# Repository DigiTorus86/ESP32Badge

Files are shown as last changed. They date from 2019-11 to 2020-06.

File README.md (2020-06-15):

# ESP32Badge
Source code and resources for the ESP32 Conference Badge

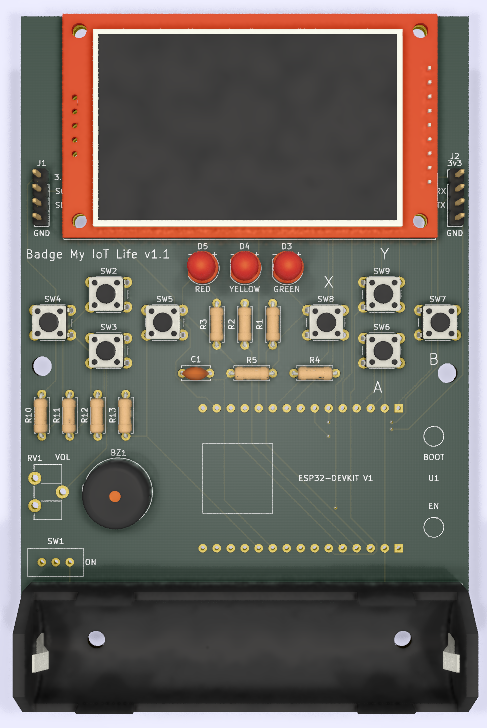
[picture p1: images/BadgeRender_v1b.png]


Requires the ESP32 conference badge or similar hardware:
- PCB:  https://www.pcbway.com/project/shareproject/ESP32_Conference_Badge_v1_2.html
- ESP32 DEVKIT v1 w/30 pins or DevKitC w/38 pins (other ESP32 boards can be used with minimal PIN changes)
- ILI9341 320x240 TFT
- [8] Tactile momentary buttons
- [4] 4k7 resistors (button pullups)
- [3] 5mm LEDs (one each of red, yellow, green)
- [3] 100R resistors (LED current limiters)
- small speaker/active buzzer  (8 Ohm / 2 Watt)
- CR18650 battery and battery holder are optional
- Some sketches have additional hardware requirements (components attached to I2C or Serial pins, or SD card)
- PCB is available at PCB Way for order:
  https://www.pcbway.com/project/shareproject/ESP32_Conference_Badge_v1_2.html

Required Libraries for Arduino platform sketches:
- Adafruit GFX
- Adafruit ILI9341
- ArduinoJson
- XTronical XT_DAC  https://www.xtronical.com/the-dacaudio-library-download-and-installation/

Example Sketches:
- Basic:  4 Simple badges combined into one (Marquee, Hello, Hello w/changing message, Gangster wanted poster)
- Framework Only:  Starter sketch with only pin defines, component setup, and button checking.
- Gravitack:  Low-gravity lunar lander type game
- QR Code:  Name badge with QR code display of the ESP32 IP address and simple web page for controlling the LEDs
- Slideshow: Timed slideshow display.  Requires v1.2 of the badge with 38-pin DevKitC and an SD card.
- Test1:  Test app to verify functionality of the badge.  Also available for the ESP-IDF platform. 
- Test BLE Peripheral/Central:  Shows how to use one badge to control another over BLE.
- Time & Weather:  Displays time and weather data from DS3231 RTC and BME280 temperature/humidity/pressure sensor via I2C as well as network weather info
- Tombstone:  Classic Morg-shooting schooner game
- Wizard:  Animated badge for wizards and witches that have escaped from notorious magical prisons

Accessories:
- Kickstand:  Minimalist 3D-printed kickstand for the badge to get it to stand upright on a flat surface.  Attach to the middle holes on badge (just below the buttons) with 2 small flat-headed woodscrews.
- Case bottom designed by Gino Melone:  https://www.tinkercad.com/things/hnff6LtKR47

Scripts:
- img-rgb565.py: convert graphics files to RGB565 bitmap integer array C header files
- wav-pcm8.py: convert 8 bit mono PCM wave files to byte array C header files 

Additional Info:
- The TFT display orientation is rotated 180 degrees between the v1.1 /DevKitv1 board and v1.2 DEVKITC versions.  Adjust the SCREEN_ROT value in esp32_badge.h to 1 for v1.1 or 3 for v1.2 boards.  
- SD card slot on the TFT is not connected in v1.1

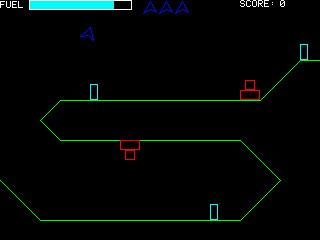
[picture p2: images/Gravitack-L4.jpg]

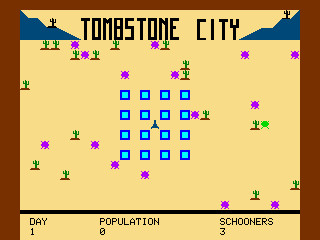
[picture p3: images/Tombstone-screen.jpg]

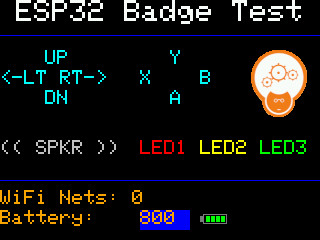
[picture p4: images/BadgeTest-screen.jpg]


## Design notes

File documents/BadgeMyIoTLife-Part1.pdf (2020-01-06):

# Badge My IoT Life - Part I

Paul Pagel

# About Paul Pagel

- 20+ years of developing software professionally
and managing software teams
- Manufacturing Systems Architect at First Solar, Inc.
- Martial arts instructor, former infantry reserve officer
- Particular area of electronic/hardware interest = Audio & Video
- Email: pjpagel86@gmail.com

# Session Objectives

Learn/review the basics of working with electronics and microcontrollers
- Terminology
- Schematics and pinouts
- Soldering and assembly techniques
- Testing and troubleshooting hardware
Build and test a working wireless-enabled conference badge!

# Session Guidelines

- This is an interactive workshop. Be an active participant.
- If I ask a question to the group, go ahead and call out the answer.
- If you have a question, raise you hand…the sooner the better.
- Acronyms and abbreviations - now in nested varieties...
- Work with the session assistants and participants around you during the assembly and testing process. Leverage the wisdom of teams.
- Be respectful of your fellow attendees and keep side conversations to a minimum during the lecture portions.
- Set phones on vibrate and step out to take calls.
- Have fun!

# The Badge

Begin with the End in Mind

# The Badge

### - Think hackable internet-enabled Game Boy with options to add your

own sensors and accessories.

### - Can expect 6 to 8 hours of operation with a fresh, fully-charged

battery.
- Layout facilitates easy soldering.

### - Designed so that key components can be removed and reused in other

projects.

# The Badge – Capabilities

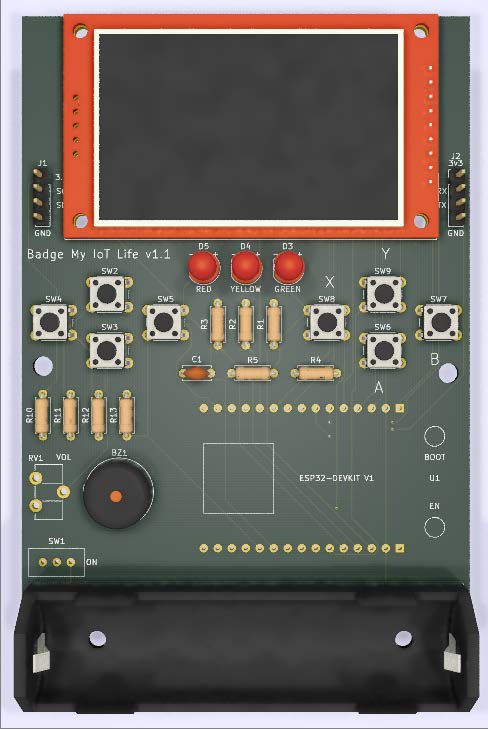
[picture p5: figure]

- Relatively large 262K color display - WiFi and Bluetooth/BLE (Bluetooth Low Energy) connectivity - Lots of buttons for user input - Can be powered from battery or USB - Battery level detection circuit - Digital audio/WAV file output to speaker - Jumpers for Inter Integrated Circuits (I2C) bus and Universal Asynchronous Receive Transmit (UART)

# The Badge – Limitations

### - Rather bulky compared to coin cell

powered badges with e-Ink displays.

### - Don’t expect 60 Hz display refresh (closer to 1 Hz for full screen) - Fairly quiet, low-fidelity sound from

the button speaker/transducer.

# The Badge Tester App

### Allows you to easily exercise all the buttons and peripherals on the badge

and detect any problems.

### Comes pre-loaded onto the

microcontroller included in the kits.

### This should be the first thing you see when you power on your completed

badge.

# Microcontrollers

A Quick Overview

# Microcontrollers

### Microcontroller: A small computer on a single integrated circuit often used in embedded applications. Also referred to as a Micro

Control Unit or MCU.

A few common examples:
- Atmel AVR
- ARM Cortex M-series
- ESP8266 / ESP32-Wroom-32 Come in a number of form factors
- Dual Inline Package (DIP)
- Surface Mount Devices (SMD)

# Development Boards

### Dev boards are designed to make the MCU easier to evaluate and to

use in small scale custom designs.

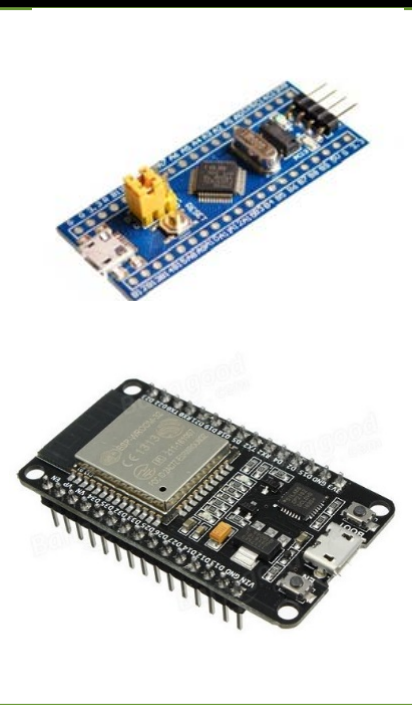
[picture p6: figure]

### Common examples: - Arduino Uno - Adafruit Feather

### - STM32F103 “Blue Pill” - ESP32 Dev Kit

# Meet the ESP32 DevkitC/NodeMCU-32S

## Processing power and memory

### - Espressif ESP WROOM-32D MCU

### - Dual-core 32-bit Tensilica Extensa LX6 processor @ 160 or 240 MHz - 448KB ROM, 520KB SRAM, 4MB Flash

In Kit:
- 1 – ESP32 DevKitC w/38 pins

# Meet the ESP32 DevkitC/NodeMCU-32S

## Excellent connectivity capabilities

### - 2.4GHz dual-mode WiFi + Bluetooth 4.2 + BLE

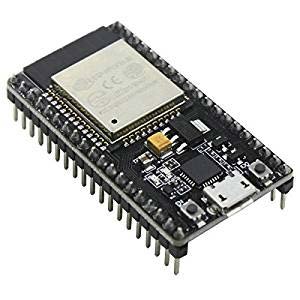
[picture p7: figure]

### - Support for security and encryption

# Meet the ESP32 DevkitC/NodeMCU-32S

## Many built-in peripherals

### - Integrated UART, SPI, I2C, I2S, CAN, PWM

### - 18-channel 12-bit Analog-to-Digital Converter (ADC) - 2-channel 8-bit Digital-to-Analog Converter (DAC) - 30+ General Purpose Input Output pins (GPIO)

# Electronic Components

What’s in the Kit and What It Does

# Printed Circuit Board (PCB)

### - Contains attachment points / through-holes for components and the wiring traces to

connect them.

### - Silk screen identifies the location and

orientation for components to be soldered.

### - Allows for quicker assembly, fewer mistakes, and smaller footprint compared

to proto or strip board.

In Kit:
- 1 – custom PCB (v1.2)

# PCB Structures

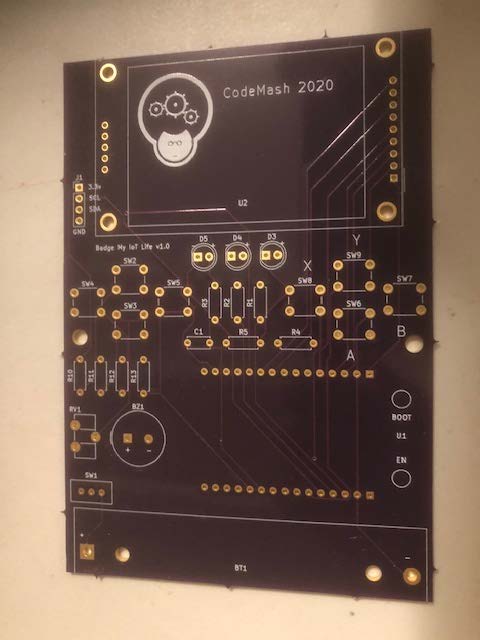
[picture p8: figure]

### Solder Mask - Top layer that repels solder and protects the traces - Often contains lead, so don’t lick it

# PCB Structures

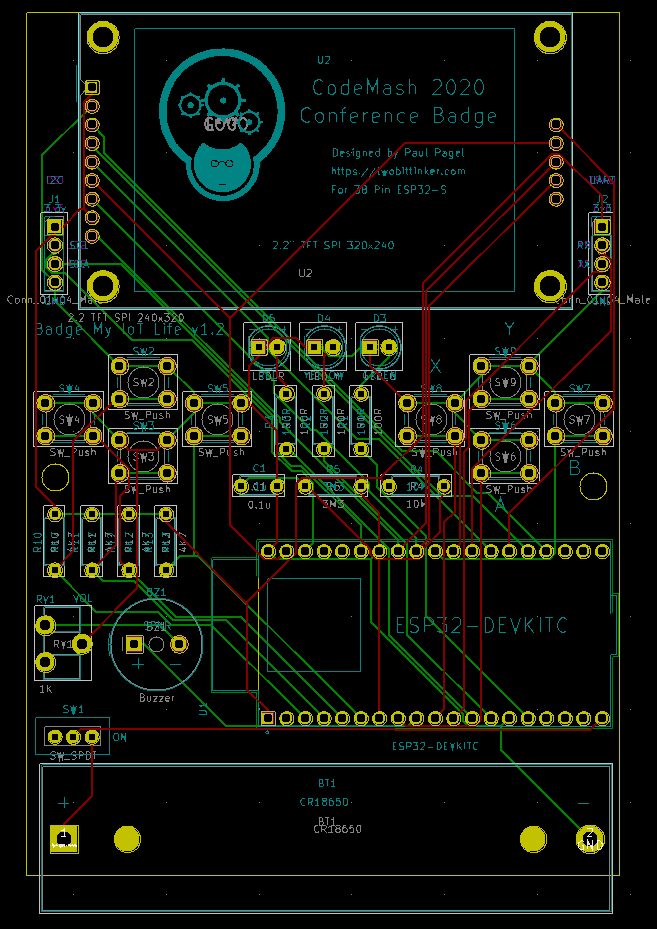
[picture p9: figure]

### Traces - Copper wires that connect the solder pads/rings - The badge board has 2 layers of traces (front & back) - Traces can be damaged

# PCB Structures

### Through Holes

### - Mounting holes: large, may or may not have metallic annular rings. Used to

connect cases, peripherals, etc.

### - Component holes: sized to accommodate component wires (~22 gauge) and always have an annular ring

for soldering.

### - Vias: smaller holes that allow the traces to carry current from one layer to another. Not for soldering!

# Schematic v1.2

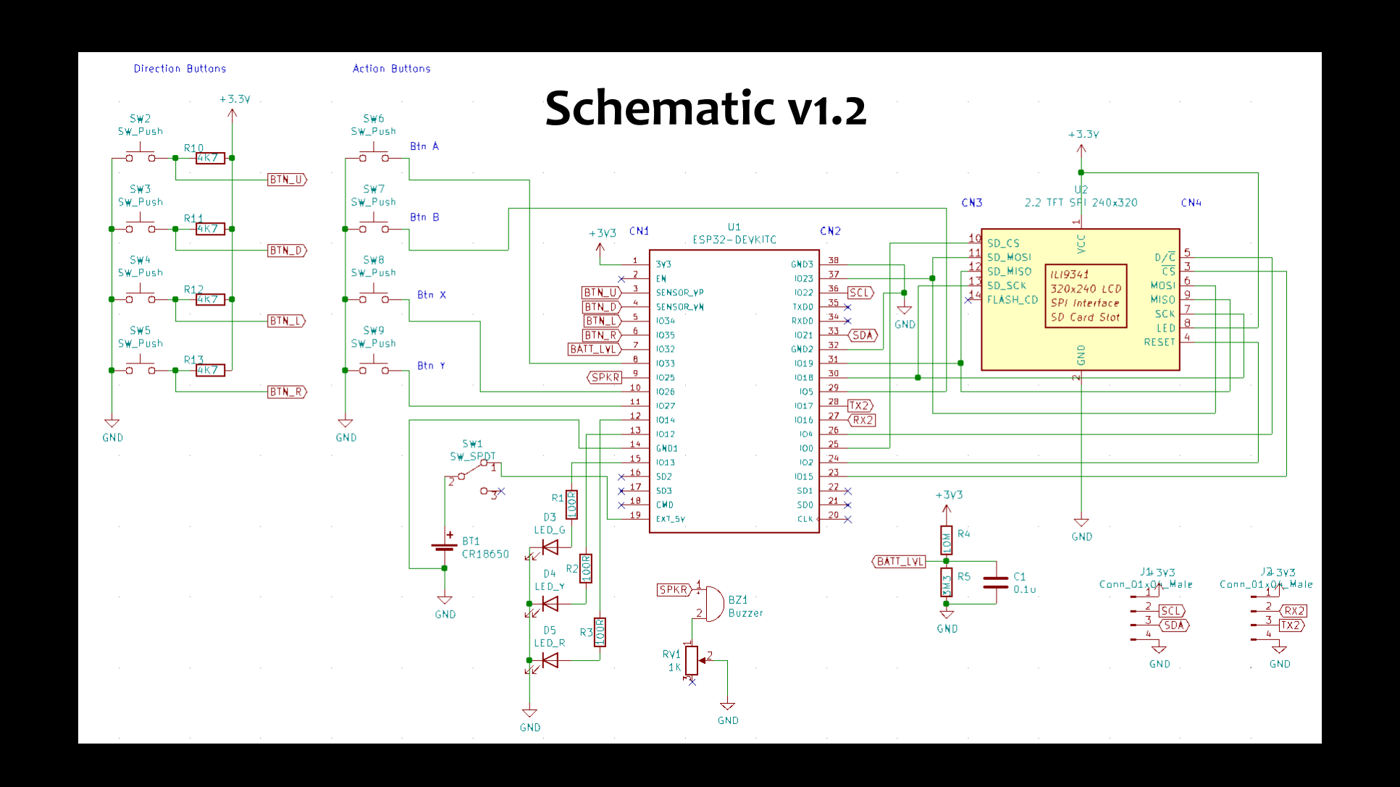
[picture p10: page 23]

# Matching the Schematic to the PCB

### - The schematic can help identify the role of each component on the PCB - Component identifiers on the schematic match up to those on the PCB and BOM (Bill of Materials)

SW1 = Switch1, R1 = Resistor1, C1 = Capacitor1, etc.

### - Schematic circuit is easier to follow than the traces on the PCB and is useful for diagnosing problems or determining if a substitute component can be used - The physical pin layout on the PCB may be different from the logical pin layout on the schematic

# TFT LCD Screen

### Thin Film Transistor (TFT) Liquid Crystal Display (LCD)

- Usually have a specific control chip, i.e. ILI9341
- Often include an SD card reader on the back
- May or may not have touch capability (T_ pins)
- Often use Serial Peripheral Interface (SPI) protocol for communication with the MCU
- Frame rate vs low resource utilization tradeoffs

In Kit:
- 1 – TFT LCD, 2.2” 320x240 w/integrated ILI9341 SPI
controller, 3.3v, 262K colors [U2]

# 18650 Lithium Battery

### 3.7 v lithium rechargeable battery - 18650 indicates 18mm diameter x 65mm height - Voltage output range is 4.2v – 2.5v, which pairs nicely with 3.3v MCUs - Capacity is measured in mAh (milliamp hours) and maximum continuous

discharge in Amperes.

### - These are inversely related. Generally

favor capacity for MCUs.

In Kit:
- 1 – 18650 3.7v rechargeable battery

# Battery Holder

### Holds battery in place and provides electrical connection between battery and circuit board Polarized – pay attention to + / -

In Kit:
- 1 – 18650 battery holder [BT1]

# TP4056 Battery Charger

### 5v 1A micro USB board for recharging CR18650 batteries

- Allows you to charge the battery without having to remove it from the badge
- Optional – not required

In Kit:
- 1 – TP4056 charging module
- 2 - hookup wires (+ / -)

# Piezo Buzzer/ Electrodynamic Speaker

### Generates tones or other sounds

Two general types
- Active – generates tones based on DC voltage
- Passive – requires oscillating input to convert to sound Polarized – positive leg marked with a (+) on top or bottom

In Kit:
- 1 passive speaker
(polarized) [BZ1]

# Resistors

### Passive device used reduce current or divide voltages

- Non-polarized (no right or wrong orientation)
- Measured in Ohms
- 100R indicates 100 Ohms
- 4K7 indicates 4,700 Ohms
- 3M3 indicates 3,300,000 Ohms
- R10 – 13 can be 2k – 8k Ohm
- R1-3 can be 100 – 330 Ohm

In Kit:
- 4 – 4k7 [R10-13]
Ye-Vi-Bk-Br
- 3 – 100R [R1-3]
Br-Bk-Bk-Bk
- 1 – 3M3 [R5]
Or-Or-Bk-Ye
- 1 – 10M [R4]
Br-Bk-Bk-Gr

# Breaking the Code

### Many mnemonics available. One example: Bright Boys Rave Over Young Girls But Veto Getting Wed

When in doubt,

### measure with a

multimeter.

# Potentiometers

### Variable resistors

- Can be rotary (dial) or linear (slide)
- Middle leg is connected to the wiper (C)
- Markings indicate maximum resistance
- First 2 digits x 10^3rd digit
- 501 = 50 x 10^1 = 500 Ohm
- 102 = 10 x 10^2 = 1k Ohm

For the badge, any value from 500 to 2000 Ohm will work.

In Kit:
- 1 – 1K pot
[RV1]

# LEDs

### Light Emitting Diodes

- Polarized - orientation is critical
- Longer leg = positive
- Flat side = negative (may not be present)
- Popular sizes are 3mm, 5mm, and 10mm
- Usually require a current-limiting resistor

In Kit:
- 1 – Red [D5]
- 1 – Yellow [D4]
- 1 – Green [D3]

# Capacitors

Passive devices that store electrical energy
- Some types are polarized, others are not
- Ceramic = non-polarized
- Electrolytic = polarized
- Measured in Farads
- nF = nano Farads (1 billionth)
- uF = micro Farads (1 millionth)

In Kit:
- 1 – 100nF / 0.1uF ceramic capacitor [C1] (usually marked with a “104”)

# Buttons and Switches

Mechanical devices for opening and closing a circuit
- Momentary vs. Latching
- Normally Open (NO) vs. Normally Closed (NC)
- Poles = number of circuits connected
- Throw = number of positions (on/off is single)

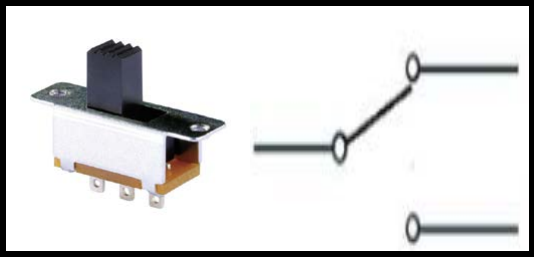
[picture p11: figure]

SPDT slide switch
(Single Pole Double Throw)

Tactile momentary
NO button
(Normally Open)

In Kit:
- 1 – SPDT slide switch (power) [SW1]
- 8 – momentary NO buttons [SW2 - 9]

# Header Pins

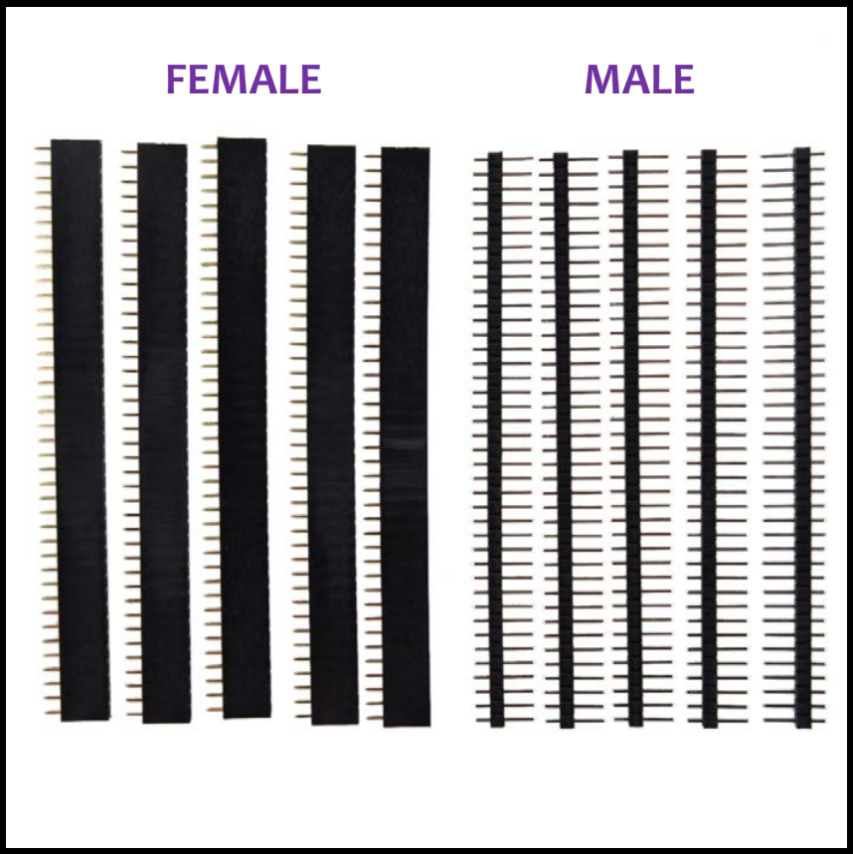
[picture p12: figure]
FEMALE; MALE

Connect controllers, breakout boards,

### major components, and jumpers

- Come in male and female varieties.
- The short end goes into the PCB

In Kit:
- Female header pins
- Male header pins

# Soldering

Bringing the Heat Without Getting Burned

# Soldering Iron

- Tip needs to heat up to about 700F / 370C before use.
- Keep the tip lightly tinned (shiny) but not gobbed with solder.
- Use the scouring pad to remove excess solder from the tip.

# Soldering Iron

### Safety

- Only pick up by the handle.
- Practice good tip control at all times - no balancing, waving, or gesturing with the iron. It’s not a wand.
- Keep cords clear of obstacles.
- Don’t set down on table – always use the provided stand.
- Don’t hand it to another person. Let them pick it up.
- Turn the iron off/unplug before leaving your station.

# Solder

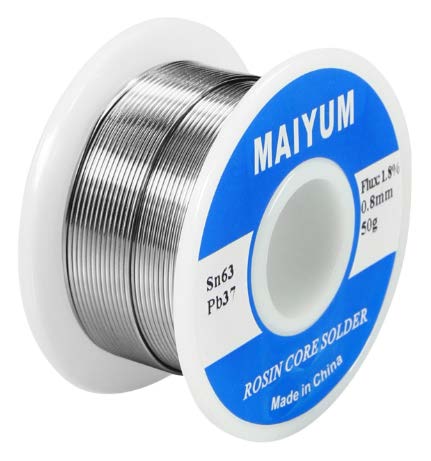
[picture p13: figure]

- Most common solder for hand-soldering is a mix of tin (~60%) and lead (~40%)
- Rosin core allows the melted solder to flow smoothly onto the pads and wires
- Rosin has the downside of producing smoke that is a lung irritant – avoid inhaling.
- Lead-free wire is available, but requires a higher melting temperature and is more difficult to work with.

# Soldering Technique

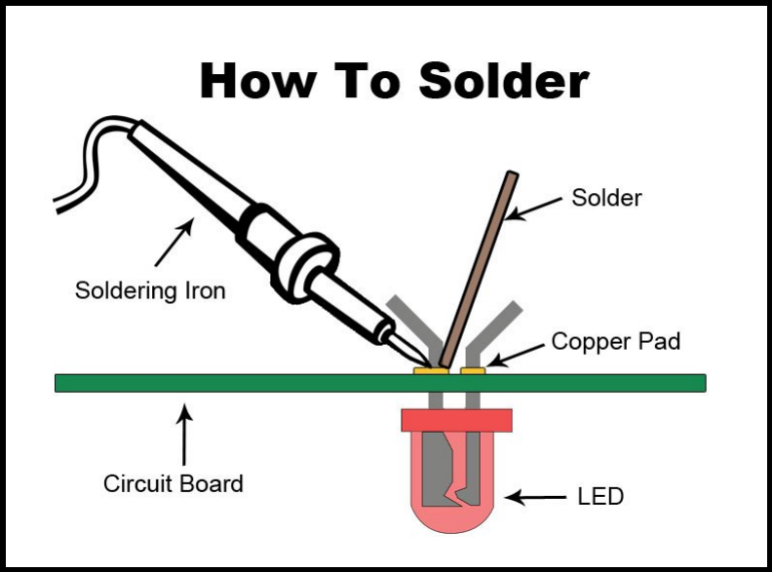
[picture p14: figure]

- Heat both of the elements that you are soldering (i.e. the solder pad and the component wire) for a few seconds, then apply the solder.

Solder flows towards heat!
- Don’t keep applying heat to components for more that a few seconds or you may damage them.

# Soldering Technique

- Ensure you have a smooth, shiny, volcano-shaped join and that all
the gaps are filled in.
- Watch out for solder
bridges/shorts to other pads or components.

# Soldering Technique

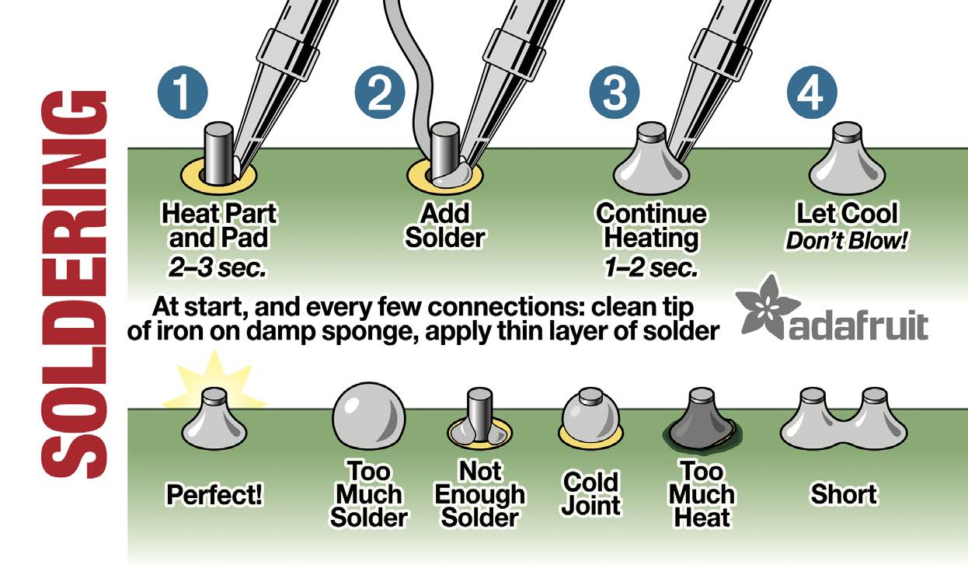
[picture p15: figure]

# Flush Cut Pliers

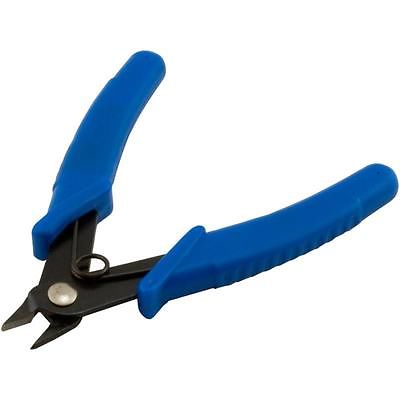
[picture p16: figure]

### Trim component lead wires after soldering

- Leads and pins often separate at high speeds and go flying, so cup them with your hand and don’t point them at your eyes while using.
- Keep wire cuttings and waste in your plastic cup – not scattered around on your table.

# Desoldering

Dealing With “Oops!”

# Desoldering Pen (aka Solder Sucker)

### Used to suck away solder when removing

soldered components.
- Use the plunger to prime the pen, and the button to perform the suction operation.
- Requires a bit of precision and timing as nozzle needs to be pretty close to the liquefied solder and triggered before the solder starts to solidify.
- Often requires multiple attempts to get most of the solder.

# Desoldering Braid/Wick

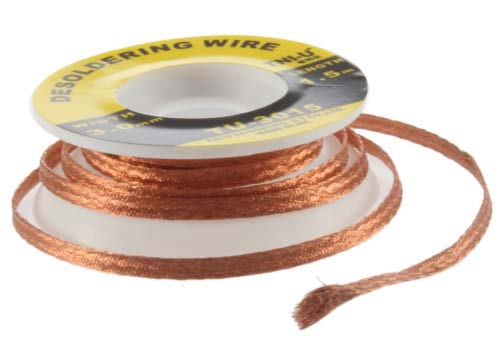
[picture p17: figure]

### Used to pull away solder when removing

soldered components.
- Use a section of the braid without solder on it.
- Heat the solder through the braid to get the solder to melt and flow onto the braid and then pull it away from the area.

Remember, solder flows towards heat.

# Desoldering

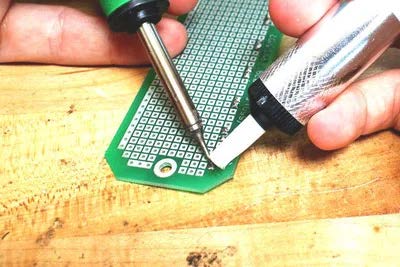
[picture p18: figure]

1. Reheat the joint and get as much solder away from it as you can using a desoldering pump.
2. Alternatively, heat joint through a soldering wick/braid to get the solder to stick to the wick.
3. Use a pliers to gently pull the component wires from the board.
4. Reheat and remove any excess solder that is still left using solder braid.
5. Insert and solder the replacement component.

# For a More Pleasant Experience…

- Take your time. This isn’t a race. No points awarded for finishing first.
- Help others around you. No soldier or (solderer) gets left behind.

### - Cup up = working on badge - Cup down = done and good to go Please put your trimmings/waste in the garbage can first!

# Assembling the Board

Putting It All Together

# General Assembly Guidelines

- Keep parts segregated to avoid confusion (especially resistors)
- Start with the smaller/shorter passive components and work towards the larger ones
- Bend resistor leads to a 90 degree angle as close to the body as possible
- If you’re not sure about a resistor’s value, use a multimeter to test it.
- Pay close attention to polarity! (LEDs, speaker, battery)
- Even though orientation doesn’t matter for non-polarized components (like resistors) it’s easier to identify them on the board if you orient them consistently.
- Check twice, solder once – always on the back of the board. Desoldering is a bit of a pain.
- Don’t trim leads until after you’ve soldered and inspected them
- Use magnification to check for breaks, shorts, solder bridges, splashes, etc.

# Detailed Assembly Instructions - 1

1. Identify the (4) 4.7K Ohm button pull-up resistors (yellow, violet, black,
brown) . Place them in the board,
bend the ends out slightly, and solder in place.
2. Next the (3) 100 Ohm current-limiting resistors (brown, black, black, black) for the LEDs
3. Then the 3M3 (orange, orange, black, yellow) and 10M resistors (brown, black, black, green) and the .1 uF ceramic capacitor for the battery level voltage divider
4. Solder, inspect, and trim leads.

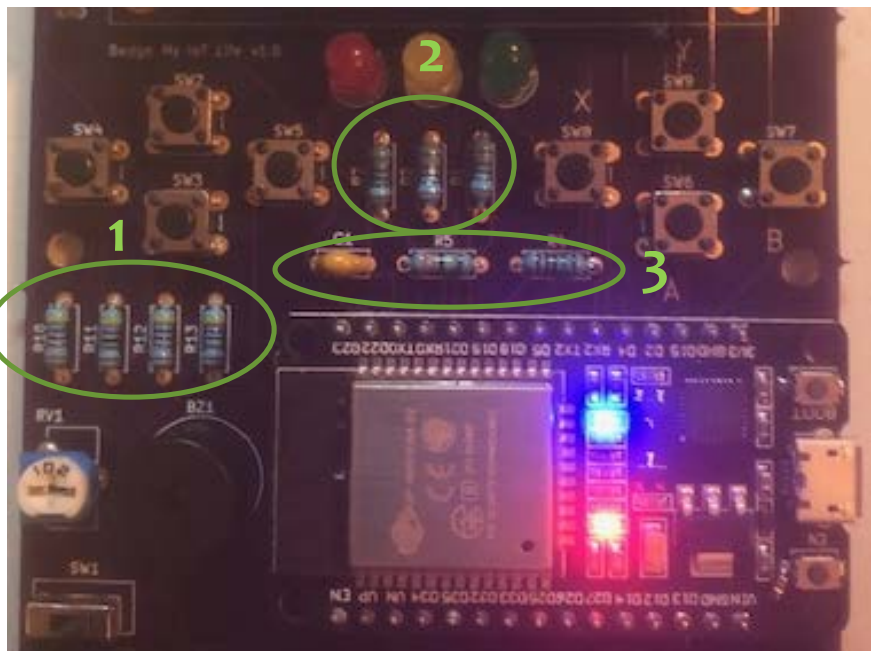
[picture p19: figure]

# Detailed Assembly Instructions - 2

5. Place the 4 direction and 4 action
buttons. The buttons will only fit with
the legs oriented left/right.
6. Insert the 3 LEDs as shown. Make sure the longer leg goes to the hole on the right (marked + )
LEDs can be destroyed by too much heat, so don’t keep the soldering iron touching the led leads for more than a few seconds at a time.

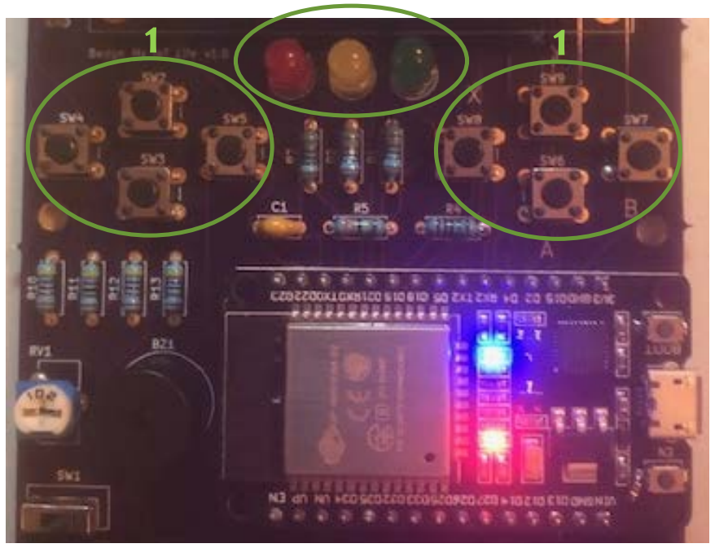
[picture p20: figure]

7. Solder, inspect, and trim leads.

2

# Detailed Assembly Instructions - 3

8. Add the on/off SPDT switch.
Don’t worry about polarity.
9. Insert the 1k Ohm trim pot (102)
10. Add the speaker. Pay attention to the polarity (+ lead to + hole) You may want to cover the
speaker hole with a piece of cellophane tape to increase volume.
11. Solder, inspect, and trim leads.

1

# Detailed Assembly Instructions - 4

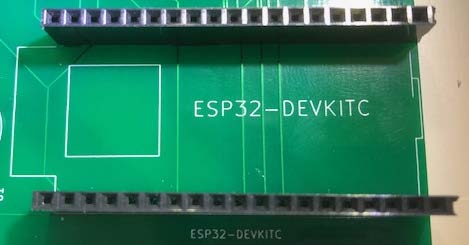
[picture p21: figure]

12. Insert one row of pins on the
ESP32 into the female header
pins as shown. Trim to header to
proper length (19 pins for v1.2)
13. Repeat for other row of pins on the ESP32.
14. With the female header pins attached to the ESP32, insert them into the board with the USB port to the right. Painter’s tape is useful to hold the ESP32 in place as you solder the header pins.

# Detailed Assembly Instructions – 5

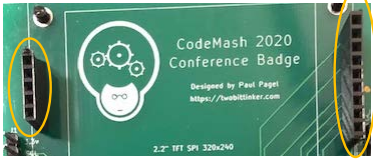
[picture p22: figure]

15. Cut male and female header pins
for the TFT display.
16. Insert the male pins into the female pins, then place the TFT over the short ends of the male pins and solder them to the TFT. It will help to have the ends of the female pins inserted into the board as you solder the TFT.
17. Flip the board over and solder the female pins to the board. Painter’s tape may help to hold everything in place.

# Detailed Assembly Instructions - 6

18. Solder the battery holder to the
board. Mind the polarity ( + to
the left) Suggest marking
polarity with metallic marker. Go fairly heavy with the solder as this part will be subject to mechanical stress.
19. Take a 4 pin male header for the I2C bus and solder to the left of the TFT.
20. Take another 4 pin male header for for the RX/TX header on the right and solder in place.

# Detailed Assembly Instructions - 7

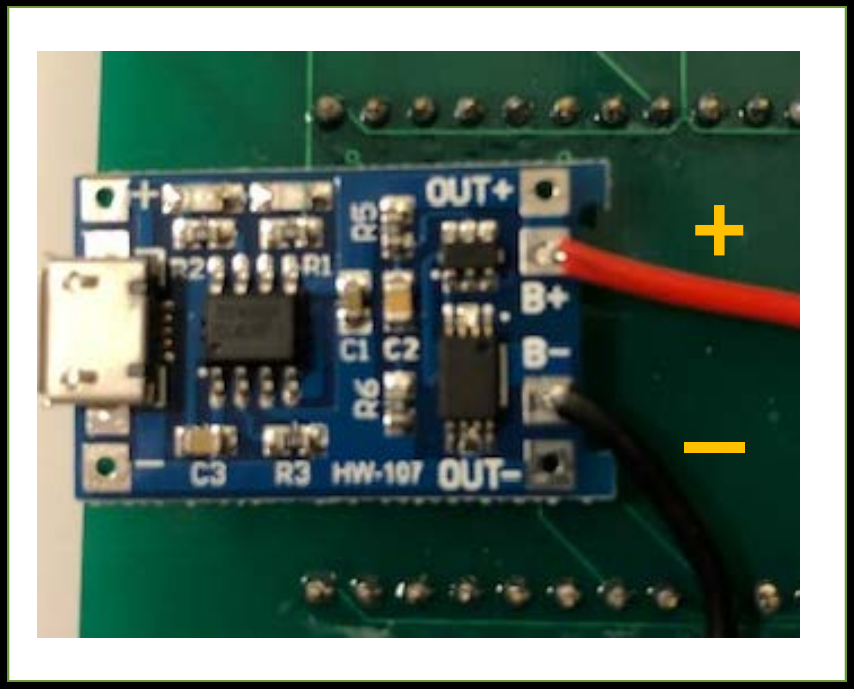
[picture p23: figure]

### OPTIONAL – Battery Charger

21. Solder the positive lead wire to the B+ pad on the TP4056 module, and the negative lead to the B- pad.
22. Stick the TP4056 to the back of the badge using double-sided tape.
23. Solder the wires to the corresponding battery holder terminal. Note that positive is on the right when looking at the back.

# Final Check

### Before energizing your badge, double-check: - ESP32 orientation (USB port to outside of board) - Battery holder and charger polarity are correct and clearly marked - All wires and pins have been soldered - No solder bridges are present

### Have one of the session assistants or an experienced neighbor

perform a final check on your board.

# Testing

Keep Your Fingers Crossed

# Booting the Assembled Board

1. Hook up the ESP32 controller to
your laptop or 5v / 1A DC power
source using the Micro USB
cable.
2. The badge test app should boot up after a few seconds.
3. If not, try pressing and releasing the EN button below the micro USB port.

# Testing the Assembled Board

1. Network count will be 0 initially. Battery level should be around 800 or higher and stable. Zero or a wildly fluctuating value indicates a problem.
2. Press all the buttons and verify that the corresponding element is highlighted on the screen while the button is pressed.
3. The following buttons have additional actions that should be triggered:
- X: Red LED
- Y: Yellow LED
- A: Green LED
- B: Tone should play through the speaker
4. You may need to adjust the trimpot to get the desired volume. Counterclockwise = Louder (Be gentle – don’t force it!)

# Testing Battery Operation

1. Disconnect the USB cord from the ESP32.
2. Ensure the power switch is in the “Off” position (all the way to the left)
3. Place the loop of ribbon across the battery holder perpendicularly. (Not required if you have exceptionally strong fingers or enjoy the challenge of battery extraction.)
4. Take a charged CR18650 battery and insert it with the positive end pointed towards the left side of the board and firmly seat in place.
5. Move the switch to the “On” position.
6. Repeat the previous button test.
7. Verify that the battery level indicator is lower than what was shown in the previous test. Usually it will be under 1000.

# Troubleshooting – Dead Board

### If you get no response from the badge at all:

- Remove the ESP32 from the badge and see if the power light comes on when hooked up to your laptop via the USB cable
- Ensure you have the ESP32 oriented on the board correctly with the USB port to the right
- Swap your ESP32 with a different one
- Swap out your TFT display
- Swap out your USB cable
- Connect the USB to a 5v 1A transformer (i.e. iPhone charger) instead of your laptop

Change only 1 element/test parameter at a time.

# Troubleshooting Components

If the badge works, but one or more particular components are non-functional:
- Re-examine the solder joints, looking for shorts/solder bridges (preferably under magnification)
- Scrub the back of the board lightly with a brush to remove an fine solder splashes/shorts.
- Ensure you have the polarity correct (battery, LEDs)
- Re-heat/re-flow the solder for the non-functional component
- Verify the component using a multimeter
- Look for discolorations that indicate an LED is burned out
- Test LEDs using a regulated power source.
- Swap out the component with a verified operational one

Use the schematic to help identify the components that may be involved in the failure!

# Charging Your Battery

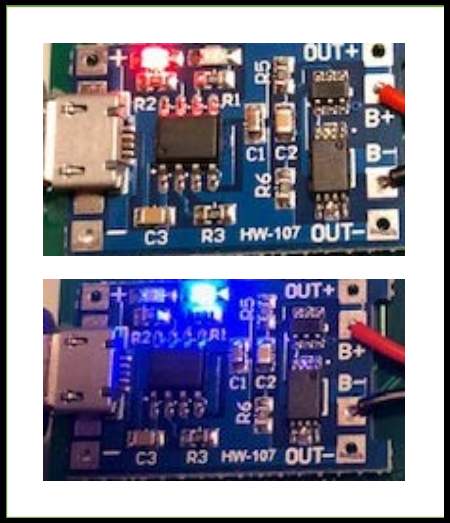
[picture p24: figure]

1. Connect a micro USB cable to the charger and a 5v DC power source.
2. LED on the charger will show red when charging.
3. The blue LED will come on when the battery is fully

-charged.

The charger has built

-in overcharge
protection, but should *not* be used to drive loads while charging (which would negate this feature).

Charging

Charged

# Finishing Touches

- Snap in the black plastic badge hanger to the top 4 holes on the back of the badge.
- Clean up your area and put your trimmings/waste in the garbage.

# Interface Protocols

A Small Byte of Serial

# Common Interface Protocols

### Standardized methods and wire layouts for communicating with other systems, peripherals, and sensor breakouts

Common examples:
- UART
- SPI
- I2C
- I2S
- CAN
- USB
- USART
- 1-Wire

# Common Interface Protocols

Do not confuse connector standards with the underlying protocols.

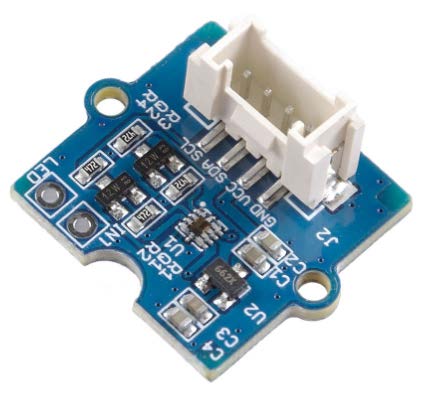
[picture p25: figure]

- Grove
- Qwiic
- Gravity
- MikroBUS
- JST

# Parallel vs Serial

### Parallel requires a pin/wire for every bit

### Serial sends data for a channel over the same pin/wire

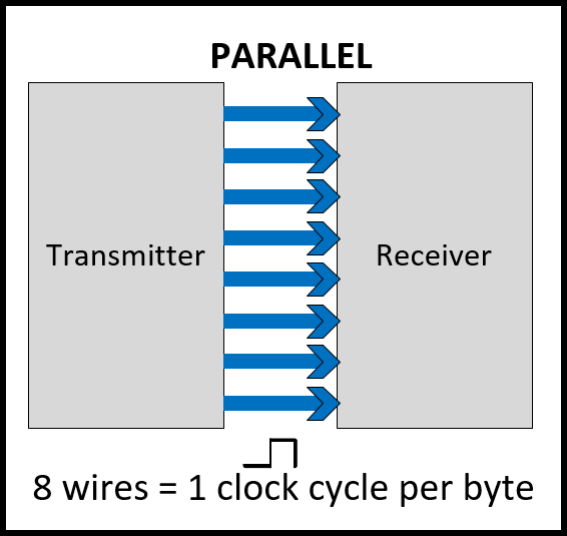
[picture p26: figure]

Serial protocols tend to be much more common with microcontrollers.

# Serial Protocol Hardware Pins

# Universal Asynchronous Receive Transmit (UART)

- Takes bytes and serially shifts them to the receiver,
which then assembles them back into bytes.
- May be simplex (one direction only), half-duplex (one direction at a time), or full-duplex (both directions at the same time)
- Most microcontrollers use full-duplex with separate RX/TX lines
- Must configure both sender and receiver with the correct baud rate.
- May also have options for different data bits, bit
parity, stop bits, and handshakes.

https://core-electronics.com.au/tutorials/serial-communications-arduino-uno.html

# UART – Usage Considerations

- Ubiquitous and easy to use
- Often used for debugging and simple data transmissions between devices
- Other common peripherals include RFID readers, fingerprint scanners, MIDI ports, and BLE adapters.
- Serial UART output can be monitored with a number of standard tools: Arduino Serial Monitor, VS Code terminal, TeraTerm, etc.
- USB to TTL (Transistor Transistor Logic) level UART cables used to program and debug many microcontrollers.

# UART on ESP32

- ESP32 devkit board has 2 UART peripherals broken out (UART 0, UART 2)
- In Arduino environment, initialized with: Serial.begin(baud_rate);
Serial2.begin(baud_rate);
- Unmatched baud rates = garbage data received Pay attention to your serial console/monitor settings:
- On the badge, Serial is accessed through USB and Serial2 via jumper to the right of the TFT

# Serial Peripheral Interface (SPI)

### SPI Pins:

- SCK: Serial Clock (hi/low pulse)
- MOSI: Master Out Slave In
SDI = Slave Data In
- MISO: Master In, Slave Out
SDO = Slave Data Out
- SS: Slave Select or CS=Chip Select ~, n, or bar indicates active low
- Vcc and GND are always assumed
- May have an INT (interrupt) pin
SPI devices can share the same GPIO pins - except for SS

# SPI - Usage Considerations

- Commonly used for displays (TFT, OLED, e-Ink, etc.), storage/SD, lower-end audio applications
- Is full-duplex, so can send and receive data at the same time
- Is synchronous and can use a range of clock frequencies
- Comes in 4 different “flavors” depending
on clock phase and polarity

# SPI on ESP32

Arduino environment uses SPI.h library
- ESP32 has 4 SPI peripherals
- SPI0 & SPI1 used internally
- SPI2 = HSPI, SPI3=VSPI
- Badge uses VSPI
- SS can be any digital GPIO pin
- Most common devices have existing libraries that take the SPI pin
assignments as a constructor

https://learn.sparkfun.com/tutorials/serial-peripheral-interface-spi/

# SPI on Screen

The ILI9341 display adds a couple extra pins to the SPI interface:
- LED: power/brightness for the screen backlight LED
- DC/RS: Data Command/Register Select – tells the TFT the nature of the bits coming across MOSI wire Low = Command
High = Data / Command Parameter
- Reset: Resets the display when low There are also SPI pins for the SD card
(SD_xx) and optional SRAM chip (F_CS)

http://www.lcdwiki.com/2.2inch_SPI_Module_ILI9341_SKU:MSP2202

# Inter Integrated Circuits (I2C)

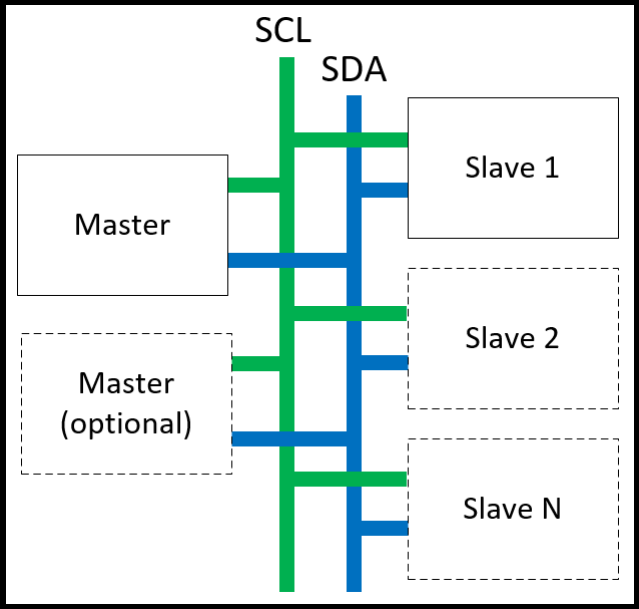
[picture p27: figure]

### Half-duplex “two-wire” serial protocol

- Master always initiates communication
- Pins
- SCL = Serial CLock
- SDA = Serial DAta
- Multiple devices (100+) can exist on the same I2C bus without any additional pins
- Each slave device must have a unique 7-bit address

# I2C – Usage Considerations

- Good for pin-constrained situations (only uses 2 wires) or when you need to control a lot of devices
- Easy to add digital IO expander and ADC chips
- Supports multiple masters with arbitration
- Often used for audio/video/camera control interfaces, but not for the data itself
- A bit more complicated under the hood than SPI

# I2C Driver

Open source hardware tool for controlling I2C devices
- Includes a TFT display of current status/activity
- GUI running on your computer is used to select addresses and read/write data

# I2C – Badge Implementation

Arduino environment uses the Wire.h library for I2C
- Normal high-level process:
Wire.begin();
Wire.beginTransmission(I2C_ADDRESS); …read and write data to/from different registers… Wire.endTransmission();
- Refer to the device datasheet for the registers and commands to read/write.
- On the badge, the I2C jumper pins are to the left of the TFT

# Pulse Width Modulation (PWM)

- Technique used to encode a value on a digital
pin based on the percentage of time the value is
high vs. low.
- The percentage of high vs. low is known as the duty cycle
- PWM is commonly used to dim LEDs, control servos, or drive an audio signal.
- Different applications require different frequencies (how often the voltage changes)
- LED dimming: 100 - 50o Hz (cycles/second)
- Motor driver: 200 – 5,000 Hz
- Audio: 44 KHz+

# Pulse Width Modulation (PWM)

### ESP32 uses the LEDC (LED Control) library

- https://github.com/espressif/arduino-esp32/blob/master/cores/esp32/esp32-hal-ledc.h
- Set up an LEDC channel with a frequency and a timer
- Attach the channel to one or more output pins for the PWM signal
- Write the duty cycle to the channel

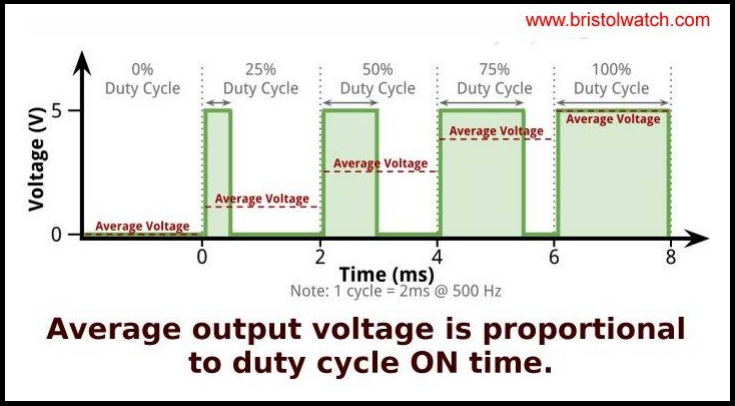
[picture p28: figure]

See the Badge Marquee sketch for an example of using PWM to dim LEDs

# Next Steps

Where do we go from here?

# Finishing Touches

- Take a picture of your completed badge for posterity (selfies will come in the next session when we load and customize the other badge apps)
#codemash2020.

- Prepare for the afternoon session:
- Ensure Arduino IDE or VS Code w/PlatformIO is installed on you laptop
- Make sure you have some image and audio editing software installed
- Check that your laptop recognizes the ESP32 when connected via USB
- Make sure you mobile phone is charged and has a QR code app loaded
- Full prerequisite instructions: http://prereqs.codemash.org/Files/Badge%20My%20IoT%20Life%20-%20Prework.pdf

# Hardware Considerations

- Recommend turning switch to OFF position when the ESP32 is connected to laptop of other power source, as well as when charging the battery via the TP4056.
- The I2C and UART pin headers on the badge support a wide variety of 3v3 peripheral devices. If you have any, you may want to consider connecting them to the badge with female DuPont connectors or soldering hookup wire to female header pins to create a custom connector.

# CodeMash Badge Contest

### Categories

### - Laugh Out Loud - Artistic Achievement - Technical Wizardry

### Bring submissions to the Maker Space before noon on Friday for consideration. CodeMash staff will take a short video, along with

your name(s) and email. Must be present Friday afternoon to win.

# Resources

- Greg Huber’s instructional videos on assembling the badge Part 1: https://youtu.be/l8pbRDcyUmc (https://nam03.safelinks.protection.outlook.com/?url=https%3A%2F%2Fyoutu.be%2Fl8pbRDcyUmc&reserved=0)
Part 2: https://www.youtube.com/watch?v=5SnY-SC2Caw
- Adafruit Guide to Excellent Soldering https://learn.adafruit.com/adafruit-guide-excellent-soldering/tools
- Instructables Ultimate Guide to Desoldering https://www.instructables.com/id/The-Ultimate-Guide-to-Desoldering/
- Espressif ESP32 WROOM-32D Documentation https://docs.espressif.com/projects/esp-idf/en/latest/hw-reference/modules-and-boards.html

# Acronyms

- ADC: Analog to Digital Conversion
- BLE: Bluetooth Low Energy
- DAC: Digital to Analog Conversion
- GND: Ground
- GPIO: General Purpose Input Output (pins)
- I2C: Inter-Integrated Circuit pronounced "I squared C" (serial bus with 2 pins: SCL, SDA)
- I2S: Inter-IC Sound (serial audio protocol with 3 pins: SCK/BCLK, WS/LRCLK, SD/SDATA)
- MCU: Micro Control Unit
- MISO: Master In - Slave Out (SPI pin) sometimes referred to as SDI on a master
- MOSI: Master Out - Slave In (SPI pin) sometimes referred to as SDO on a master
- PCM: Pulse Coded Modulation (WAV files)
- PWM: Pulse Width Modulation
- RXD: Receive Data (UART pin)
- SCK: Serial Clock (SPI pin)
- SCL: Serial Clock (I2C pin)
- SDA: Serial Data (I2C pin)
- SPI: Serial Peripheral Interface (4 pins: SCK, MOSI, MISO, SS)
- SRAM: Static Random Access Memory
- SS: Slave Select (SPI pin)
- TFT: Thin Film Transistor (Liquid Crystal Display)
- TTL: Transistor Transistor Logic (0v/LOW & Vcc/HIGH)
- TXD: Transmit Data (UART pin)
- UART: Universal Asynchronous Receiver/Transmitter (2 pin interface using RXD and TXD pins)
- USB: Universal Serial Bus
- V+ / Vbus / Vcc - Voltage positive signal (USB header pin)
- VREF: ADC reference voltage, usually 1/2 the ADC voltage range, i.e. 1.65v for 3.3v logic

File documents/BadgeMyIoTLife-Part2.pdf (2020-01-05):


# Badge My IoT Life - Part II

Paul Pagel

# Badge My IoT Life – Part II

### GitHub repo: https://github.com/DigiTorus86/ESP32Badge

### Slide Decks and Labs (PDF): https://github.com/DigiTorus86/ESP32Badge/tree/master/documents

# Session Objectives

### - What can the ESP32 badge do? - How can I incorporate my own graphics and digital media? - How do I build a personalized badge application? - How can I use the wireless capabilities of the ESP32? - What are some next steps I can take?

# Out of Scope

## This session will not:

### - Dive deep into the low-level details of MCU architecture or interface protocols - Require expertise with C or C++ (though it will help) - Make you an EE

# Disclaimers

## - Not a Mac guy - Provided_code != production_code

# Safety


- Lead is a common component in electronics, so wash hands before eating and avoid rubbing eyes.
- Keep your work area clear, especially of open liquid containers.
- Some components can be damaged by static shock, so grounding yourself after walking around is generally a good idea.
- If you see something that looks unsafe, call a stop so it can
be evaluated and addressed.

# Microcontroller Development Environments

A Quick Overview

# Arduino IDE

### Pros

- Simple to use
- Very mature
- Wide device and library support
- Many tutorials available

# Arduino IDE


### Cons

- UI is a bit dated
- No auto-complete
- Limited debugging
capabilities
- New “Pro” version looks like it will address some of these issues, but is still in alpha

# Arduino IDE Verification

### Go to Tools -> Board and verify that NodeMCU-32S is in the list

### If it is not, go to Tools -> Board -> Boards Manager… and verify that you have version 1.0.4 or higher of the esp32 board toolchain installed:


# Arduino IDE Verification

### 1. Go to Tools-> Manage Libraries 2. Select Type “Installed” and verify these libraries are shown as INSTALLED:


# Library Dependencies

### Some of the libraries have recent updates (within the last month.)

They are not needed for this workshop.

### If you do upgrade to the latest versions, make sure to install the new

additional library dependencies with them.


# PlatformIO


## Pros

### - Integrates with VS Code - Modern UI - Auto-complete - Available integrated debugging - Supports frameworks other than Arduino

# PlatformIO

## Cons

### - Can be a bit more confusing for people not used to VS Code - Fewer training resources available

# PlatformIO Setup Verification

### 1. Click the Platforms icon 2. Verify that Espressif 32 is shown


# Espressif ESP-IDF


## IoT Development Framework

### - Make and GCC based build system - Uses a different set of hardware abstraction libraries than Arduino - Requires more code but provides more flexibility

# Lab #1 Hello World!

The Time-Honored Classic

# Hello Badge

1. Create a new project with a name like “Hello_Badge” for the NodeMCU-32S
2. In the setup function, enter:
Serial.begin(9600);
Serial.println("Hello Badge");
3. Click the Upload (right arrow) icon:
4. Verify that it builds correctly and uploads to the board:

# Serial Monitor

5. In PlatformIO, click the Serial Monitor icon.

In Arduino IDE, select Tools -> Serial Monitor.

### 6. Run the app again and verify that your “Hello Badge” message is shown in the Serial Monitor window:

### Your serial begin parameter must match the Serial Monitor setting! - Try changing the speed param in the code to:

Serial.begin(115200);

### - In the Arduino IDE, this is selected from a

dropdown on the serial monitor window.

### - In PlatformIO, open platformio.ini and enter:

### monitor_speed = 115200

# About the Serial Monitor


# My Program Won’t Load!!!

### - Try again - Hold down the Boot button on the ESP32 when you see:

Connecting …___...___...

### - Verify the USB port is correct and operational (Device Manager) - Power cycle the ESP32 - Swap out the cable (just because it works for power, does not mean it will work correctly for data) - Restart the IDE

# Troubleshooting

### Invalid character compiler error

- Often happens when copying and pasting from a presentation-oriented medium (PowerPoint, Acrobat, web page, etc.) into the code editor.
- Strip out all white space in the affected area and retype (or retype the whole area)

### Missing or garbled serial monitor output

- Ensure that the Serial.begin() parameter value matches the Serial Monitor speed
- Common speeds are 115200 and 9600

# End of Hello World Exercise

If everything worked correctly, please turn your cup upside down.

### If you’re getting stuck, please ask for help!

# Colors, Fonts, & Drawing

Hey, I’ve Got Something to Say!

# Colors

### Colors are in RGB 565 format – 16 bits per pixel

### R4 : R3 : R2 : R1 : R0 : G5 : G4 : G3 : G2 : G1 :G0 : B4 : B3 : B2 : B1 : B0

### Predefined colors can be found in Arduino\libraries\Adafruit_ILI9341\Adafruit_ILI9341.h


# Colors

### Online RGB 565 color picker: https://ee-programming-notepad.blogspot.com/2016/10/16-bit-

color-generator-picker.html (https://ee-programming-notepad.blogspot.com/2016/10/16-bit-color-generator-picker.html)

# Fonts

### There are over 50 different fonts included with the Adafruit_GFX_Library To use a font, simply include the header file after the GFX include:

### #include <Fonts/FreeSansBold24pt7b.h>


### …and then set it on the TFT:

tft.setFont(&FreeSansBold24pt7b);

# Fonts

### - The Adafruit GFX Library also contains source for a utility to convert

TTF fonts to C header files.

### - Each font included increases your program size, so only pull in the

fonts you need.

### - Use the tft.setTextSize() method to set a scale factor for your font (2 is 2x bigger than font size 1, 3 is 3x, etc.)

# Fonts

# - Scaling

### There isn’t any anti

### aliasing, so a big font scaled at 1 or 2 will look a lot smoother than a small font scaled by 4

or 5.

### Font scalings shown are proportionate to the TFT’s 320x240

display.

# Drawing

### As with most graphics libraries, the Adafruit GFX library provides functions for drawing common shapes, both filled and unfilled:

- Line: | drawLine()
- Rectangle: | drawRect(), fillRect()

### - Round Rectangle: drawRoundRect(), fillRoundRect()

- Circle: | drawCircle(), fillCircle()
- Triangle: | drawTriangle(), fillTriangle()

### See Adafruit_GFX.h for full API

# Lab #2 Hello, My Name Is

Without the Sticker

# Adding TFT Output

1. Click on Libraries and add “Adafruit GFX” and “Adafruit ILI9341”
2. Add the includes (try typing them to see the intellisense in action) #include <Adafruit_GFX.h>
#include <Adafruit_ILI9341.h>

3. Add the TFT constructor before the setup() function:
Adafruit_ILI9341 tft = Adafruit_ILI9341(15, 4, 23, 18, 2, 19);
4. Add the following inside your setup() function:
tft.begin();
tft.fillScreen(ILI9341_BLACK); tft.setTextColor(ILI9341_WHITE);
tft.print(“Your Name");
5. Upload the sketch. You should see the screen go dark and display your name – though it may not look quite like you’d expect. We’ll fix that shortly.

What are
these?

# Troubleshooting

Library not found
- Make sure the library has been installed into your environment
- Use <> around the path for global includes that are not local to your project

# Adding Nicer TFT Output

6. Add the following font includes after the ILI9341 library include: #include <Fonts/FreeSansBold24pt7b.h>
#include <Fonts/FreeSansBold9pt7b.h>

#include <Fonts/FreeSansOblique18pt7b.h>

7. In setup() , replace the statements after tft.begin() with: tft.setRotation(3);

This will set the TFT rotation to landscape, like the badge.
8. Before setup(), add:
const char* my_name = “Your Name Here";

# Adding Nicer TFT Output

9. Add the following to setup(), after the existing statements: tft.setFont(&FreeSansBold24pt7b); tft.setTextColor(ILI9341_WHITE); tft.setCursor(50, 46);
tft.print("H E L L O");
tft.setFont(&FreeSansBold9pt7b); tft.setTextColor(ILI9341_WHITE); tft.setCursor(106, 68);
tft.print("my name is");
int16_t x1, y1;
uint16_t wd, ht;
tft.setFont(&FreeSansOblique18pt7b);
// Get the size of the displayed name using this font to center tft.getTextBounds(my_name, 10, 50, &x1, &y1, &wd, &ht); tft.setCursor(160 - (wd / 2), 120 + ht); tft.setTextColor(ILI9341_BLACK);
tft.print(my_name);

# Adding Nicer TFT Output

10. Upload the program. You should see something similar to:


https://github.com/DigiTorus86/ESP32Badge/blob/master/hello-badge/esp32-badge-hello/esp32-badge-hello.ino (https://github.com/DigiTorus86/ESP32Badge/blob/master/hello-badge/esp32-badge-hello/esp32-badge-hello.ino)

If you get stuck, check out the esp32-badge-hello sketch:

# Adding Digital Images

Picture This...

# Preparing Images

### 1. Edit the picture in the image editing software of your choice (GIMP, Paint.NET, PhotoShop, etc.)

2. Final dimensions should not exceed 320 x 240 pixels.
3. Save the image as a PNG or JPG file.
4. Convert the image file to an array in a C include file.

# Exporting Images to C - Online

### Use an online image conversion utility: http://rinkydinkelectronics.com/t_imageconverter565.php

# Exporting Images to C - Python

Use the img-rgb565.py utility in the scripts folder of the Github repo.

### Requires the Pillow Python Image Library. To install:

### pip install Pillow

### Usage:

### python img-rgb565.py mypicture.png

A new “mypicture.h” file will be created in the same folder.

Replace with
your file and
path.

# Displaying Bitmaps

### Use: const PROGMEM uint16_t <resource name>[<size>] =

{ <hex array data> };

### Use the drawRGBBitmap() function to display the bitmap image:

tft.drawRGBBitmap(x,
y,
(uint16_t *)bitmap_var,
width,
height);

Don’t forget
to include the
header!

# Lab #3 Add Your Picture

Selfie sticks at the ready…

# Get an Image to Edit

1. Take a selfie using your laptop camera or cellphone, or select some other image you’d like to use and open it in your image editing software.
2. Crop and/or scale the image to approximately 120 x 120 pixels.
3. Save the new image as a JPG or PNG file.
4. Convert the image to C using either an online utility or Python script. http://rinkydinkelectronics.com/t_imageconverter565.php
5. Copy the result file to your Hello_Badge sketch folder or create a new include file (tab) in your sketch and add the C image code to it.

# Get an Image to Edit

6. Add the include below the others in your main file, adjusting the filename as needed:
#include “mypicture.h”

7. Add the call to display your picture at the end of setup(): tft.drawRGBBitmap(0, 100, &mypicture, 120, 120);
8. Adjust the name display cursor x coordinate: tft.setCursor(220 - (wd / 2), 120 + ht); tft.setTextColor(ILI9341_BLACK);
tft.print(my_name);
9. If you have a long name, you may want to just use your first name or break it into two different print() calls.

# Adding Nicer TFT Output

10. Upload the program. You should see something similar to:

https://github.com/DigiTorus86/ESP32Badge/tree/master/hello-badge/esp32-badge-hello-pic (https://github.com/DigiTorus86/ESP32Badge/tree/master/hello-badge/esp32-badge-hello-pic)

If you get stuck, check out the esp32-badge-hello-pic sketch:

# GPIO Pins

The Ins and Outs

# GPIO Pins

General Purpose Input Output Pins allow the MCU to read and write from connected switches, sensors, and components.
GPIO pins should usually be designated using the pinMode() function in your setup() as:
- OUTPUT | set the output voltage, i.e. turning on a light
- INPUT | read the input voltage, i.e. reading a sensor value
- INPUT_PULLUP | read the input voltage, but use the MCU’s internal pullup resistors
Example: | pinMode(12, OUTPUT);

# GPIO Pins

The digitalWrite() function sets the value of a pin: digitalWrite(12, HIGH);

The digitalRead() gets the current value of a pin: int val = 0;
val = digitalRead(36);

When set as INPUT_PULLUP, a pin will read HIGH when the connected switch or button is open, and LOW when it is closed/pressed.
// evaluates True if button on GPIO36 is pressed if(digitalRead(36) == LOW)

# Lab #4 Adding LEDs and Buttons

Let there be lights!

# Meet the LEDs

1. Add the following at the end of setup(): pinMode(14, OUTPUT); // red pinMode(12, OUTPUT); // yellow pinMode(13, OUTPUT); // green
2. Inside loop(), add:
digitalWrite(14, HIGH);
digitalWrite(12, HIGH);
digitalWrite(13, HIGH);
delay(250);
digitalWrite(14, LOW);
digitalWrite(12, LOW);
digitalWrite(13, LOW);
delay(250);

# Meet the LEDs

3. Upload the program. The 3 badge LEDs should now be blinking on and off every quarter second.

# Pushing Some Buttons

4. Add the following at the end of setup():
pinMode(36, INPUT_PULLUP); // Up button pinMode(39, INPUT_PULLUP); // Down button
5. Add the following at the start of loop():
static uint16_t delay_ms = 250;
if(digitalRead(36) == LOW) // up pressed
delay_ms = (delay_ms > 100 ? delay_ms - 100 : 10); if(digitalRead(39) == LOW) // down pressed
delay_ms = (delay_ms < 5000 ? delay_ms + 100 : 5000);
6. Change both delay(250) to:
delay(delay_ms);

# Pushing Some Buttons

7. Upload the program. The 3 badge LEDs should still be blinking on and off every quarter second.
8. Press the Up button on the badge. The LEDs should blink faster, eventually just appearing to stay on.
9. Press the Down button. The LEDs should blink slower.

https://github.com/DigiTorus86/ESP32Badge/tree/master/hello-badge/esp32-badge-hello-btn (https://github.com/DigiTorus86/ESP32Badge/tree/master/hello-badge/esp32-badge-hello-btn)

If you get stuck, check out the esp32-badge-hello-btn sketch:

# Pre-made Badge Apps

What’s on the Menu

# Basic Bro’ Badge


### - Simple and direct, this is the simplest and fastest way to

generate a personalized badge.

### - No multimedia or programming

skills required.

### - Contains a number of different display modes that are selectable at runtime

# The QR Code Badge

### - Dynamically-generated QR code contains the network

web address for the ESP32.

### - Scanning it with your smartphone will open the web page generated by the ESP32

(This assumes the smartphone is on the same WiFi network)

### - Larger QR code displayed

when the B button is pressed.

# The Escaped Wizard


### - Displays a series of time-lapse photos to generate an animation effect - Some photo-editing skills and software

required.

# Time Lord Badge

- Displays current date, time, and weather conditions.

### - If no sensors available, uses

online forecast info.

### - Uses ESP32’s onboard Real Time Clock (RTC) - Syncs time via Network Time Protocol (NTP) - Requires additional

hardware for full features.

# Tombstone City Game


### - An homage to the classic Texas Instruments game created in 1981 by John C. Plaster - Uses PWM audio for the simple sound effects and melodies

# Gravitack Game

### - Inspired by the color vector coin-op Gravitar released by Atari in 1982 - Uses 8 bit WAV files for the sound effects - Comes with 6 levels

# Badge Framework

### A simple starter sketch (esp-32-badge-framework-only) that provides:

- The library includes needed for the TFT
- GPIO Pin usage definitions
- TFT and GPIO setup code
- Main loop that maps button pin states to “pressed” and “released” variables

# Lab #5 The Basic Bro

Are you basic?

# Get the Code

### If you haven’t already done so, download the badge code repo from GitHub to your laptop:

### https://github.com/DigiTorus86/ESP32Badge

# The Basic Bro Badge

1. Load the esp32-badge-basic sketch into the IDE
2. Build it without making any changes. This will verify that you have the needed libraries in place.
3. Change the my_name/company values to whatever you want
4. Upload the sketch to your badge and verify that it loads and runs correctly.
5. Use the X and Y buttons to cycle through the badge display modes.

# The Basic Bro Badge

6. Make some customizations:
- Open HelloRotate.h and edit the message values. The wittier the better!
- Change the _COLOR_HEADER values in Hello.h and HelloRotate.h to your favorite colors.
7. Create a 320 x 240 graphic to replace the picture in gangster.h.
Follow the same steps as the previous lab for image conversion.
8. Upload and verify everything still works.

# HTTP Client / Server

Putting the “Hyper” in Hypertext

# HTTP Client

- ESP32 client library supports standard HTTP request methods (GET, POST, PUT, PATCH)
- Supports HTTPS requests.
- HTTPClient library:
https://github.com/espressif/arduino-esp32/blob/master/libraries/HTTPClient/src/HTTPClient.h (https://github.com/espressif/arduino-esp32/blob/master/libraries/HTTPClient/src/HTTPClient.h)
- Used in the ESP32 Badge Time and Temperature sketch.
- Recognize that running the WiFi and Bluetooth radios causes the ESP32 to consume more power.

# HTTP Server

- ESP32 library provides lightweight HTTP server capabilities.
- Note that running an HTTP server continuously will drain your battery.
- WiFiServer
https://github.com/espressif/arduino-esp32/tree/master/libraries/WiFi/src
- Useful for serving up content from the ESP32, such as sensor data or camera images.
- Also useful for configuring and controlling the ESP32.

# Lab #6 QR Code & Time Badges

With HTTP Server Control

# QR Code Badge

1. Ensure your phone is charged and on the CodeMash WiFi.
2. Load the esp32-badge-qrcode sketch.
3. Enter the appropriate values for name, company, and WiFi in the main file: const char* my_name = "";
const char* company = "";
const char* ssid = "";
const char* password = "";
4. Optional: replace headshot.h with your 120x120-ish picture created in the previous lab. In drawBadge(), adjust the dimensions or name of the bitmap as needed: tft.drawRGBBitmap(0, 130, (uint16_t *)headshot, 111, 111);

# QR Code Badge

5. Upload the app to your badge, and wait for the yellow LED to turn on, then off – indicating that the badge is connected to WiFi.
6. Press the B button to display the large QR code (smaller one may work, but is more subject to lighting, reflection, and camera issues.)
7. Use the camera or QR scan app on your phone to scan the QR code.
8. Use the button displayed in the webpage on your phone to turn the green LED on and off.

IDEA: Create a new version of the sketch with the QR code containing
the URL for your personal or company website.

# Time and Weather Badge

1. Load the esp32-badge-time-weather sketch.
2. Enter the appropriate values for WiFi in the main file:
const char* ssid = "";
const char* password = "";
3. Upload sketch to verify that the badge is able to get on the WiFi and retrieve the current time and weather for Sandusky.

# Weather - Customized Forecast

### OPTIONAL: Customizing the Forecast API URL

https://www.weather.gov/documentation/services-web-api
1. Plug in your zipcode and select the city if multiple results
2. Copy the latitude and longitude from the result URL to the one below:


https://api.weather.gov/points/<lat>,<long> (https://api.weather.gov/points/%3Clat%3E,%3Clong)
3. Copy the URL value in the properties->forecast node of the JSON response
from the points URL and put this in your forecast_api_url variable assignment

# Bluetooth Low Energy

On the BLEeding Edge

# Bluetooth Low Energy (BLE)

- BLE is a lightweight subset of the Bluetooth classic specification
- Highly interoperable with mobile computing platforms

Peripheral devices

Central devices

Peripherals pair with only 1 central device at a time


The ESP32 can play any of the roles shown.

https://embedded.fm/blog/ble-roles

# BLE Roles

# BLE – Terms and Concepts

GAP – Generic Access Profile
- Controls advertising (visibility) and connection (interaction) of Bluetooth devices
- Server sends out advertising “beacons” on a configurable interval
- Sends back additional data when requested by a central “client” device

https://learn.adafruit.com/introduction-to-bluetooth-low-energy/introduction

# BLE – Terms and Concepts

- GATT specifies the structure in which profile data is exchanged
- Service: logical group of characteristics with a Universally Unique ID (UUID)
- Can be standard/predefined or custom
- Characteristic: single datapoint with a UUID
- Can be read from or written to
- Can be mandatory or optional
- Also encapsulates metadata (security, representation, etc.)
- Master device = central, often GATT Client
- Slave device = peripheral, often GATT Server

https://learn.adafruit.com/introduction-to-bluetooth-low-energy/introduction


# BLE Development

- ESP32 uses several different BLExxx.h libraries for implementing BLE client/server functionality
- Server Mode Process:
- Create server
- Add Characteristic
- Start Advertising
- Handle connect/disconnect events in callback functions
- May be useful to install a BLE app on your smartphone for verification and debugging purposes.
- Client Mode Process
- Create client
- Scan for server devices
- Pair with server
- Handle connect/disconnect/data received events in callback functions

# Lab #7 BLE Remote Control

Robot Not Included

# BLE Remote Control

1. Talk to your partner(s) and decide who is going to be “peripheral” and who is going to be “central” for the first iteration. Everyone should get a chance to do both roles. Peripheral is the badge acting as the controller (just like an Xbox™ controller)
Central is the badge being controlled (like your Xbox™ console)

Execute instructions 2-4 on one of the following two slides depending on your role.

# BLE Remote Control - Peripheral

2. Open the esp32-badge-ble-peripheral sketch and upload it to your badge.
3. The screen should look very similar to the hardware test app that was pre-loaded on your ESP32. However, there should be a 6-byte address line in orange at the bottom. ADDR: xx:xx:xx:xx:xx:xx
4. Copy the address to a piece of paper or show the screen to your central partner when they are ready to configure the central sketch. Include the colon separators.

# BLE Remote Control - Central

2. Open the esp32-badge-ble-central sketch.
3. Get the MAC address from your peripheral partner’s display and change the value of the address variable at the top of the sketch to match it:
String esp32_peripheral_address = “enter address here";
4. Upload the sketch to your badge.

# BLE Remote Control

5. The central badge should initially display list of detected BLE devices.
6. When/if it finds the configured address, it should pair – at which point the green light on both badges should come on. The yellow LED will pulse when the badges send/receive data.
7. Start pushing puttons on the peripheral badge. The corresponding indicator on the central badge display should change accordingly.
8. Switch roles and repeat steps 2-7 until everyone has had a turn with each role.

# Adding Sound

# Preparing Audio


### Export audio file as a mono 8bit PCM at

a sample rate of 44100 Hz or less.

Suggest 11025 Hz to decrease size since the badge speaker is not high fidelity.

Use: Tracks->Resample menu option

File->Export as 8-bit WAV.
- Save as type: other uncompressed files.
- Header: WAV (Microsoft)
- Encoding: Unsigned 8-bit PCM

# Preparing Audio

### Audio Sample Editing Tips - SHORT: Trim samples to shortest possible length - LOUD: Adjust samples to be as loud as possible without clipping - FREQ: Keep frequencies in the mid to upper range (no bass)

# Preparing Audio – App Export to C

### Use HxD or similar utility to export the audio file as C code

1. Open the WAV file in HxD and verify RIFF/WAVfmt as shown below
2. File -> Export -> C
3. Rename file to .h and include in your sketch
4. Use: const PROGMEM unsigned uint8_t <resource name>[<size>] = { <hex array data> };


# Preparing Audio – Script Export to C

Use the scripts\wav-pcm8.py script to generate the .h files.

### Usage:

### python wav-pcm8.py myaudio.wav

The file “myaudio_wav.h” will be created in the same folder.

# Playing Digital Audio

### To begin playing a digital audio clip:

- Download and install the XT DAC Audio library (v4.2 or higher) https://www.xtronical.com/the-dacaudio-library-download-and-installation/
- Include the library and the wave header file
#include "XT_DAC_Audio.h";

#include “myaudio_wav.h"

- Call the Play() function to initiate the sound DacAudio.Play(&myaudio_wav);

### Fill the audio buffer periodically to continue playing the sound:

DacAudio.FillBuffer();

# Lab #8 WAV Player

Lets make some noise!

# WAV Player

1. Download and install the XT DAC Audio library (v4.2 or higher) https://www.xtronical.com/the-dacaudio-library-download-and-installation/
2. Open the esp32-badge-wav-play sketch from the hello-badge folder.
3. Upload to your badge.
4. Press the B button and verify you can hear the sound clip. You may need to rotate the trimpot counterclockwise to increase volume.
5. Download or record a WAV file for your badge.
6. Follow the steps from the previous slides to save the WAV file as an 8-bit 11KHz mono PCM sample.
7. Export the file to a C array using either the HxD app or the wav-pm8.py script and add it to your sketch folder.

# WAV Player

8. Add the include directive for your sound file.
9. Add the XT_Wav_Class player declaration for this sample: XT_Wav_Class mywav_play(mywav_wav);
10. Add the following to loop() after btnA_pressed = true: DacAudio.Play(&mywav_play);
11. Modify the while condition in loop():
while (audio_play.Playing || mywav_play.Playing)
12. Upload the sketch and verify the sound is played when
the A button is pressed.

Replace with
your wav array
variable name.

# Ideas and Next Steps

Some of the ideas might even be good ones…

# Topics

### Sensors ADC/DAC Common Protocols

- I2C

### - SPI - UART Motor Control SD Cards and Data Storage

# Project-Driven Discovery

### Find something you want to do (real-world application) …something that excites you …something that you can accomplish in a 2-3 week sprint

…and figure out how to do it.

# CodeMash Badge Contest

### Categories

### - Laugh Out Loud - Artistic Achievement - Technical Wizardry


### Bring submissions to the Maker Space before noon on Friday for consideration. CodeMash staff will take a short video, along with

your name(s) and email. Must be present Friday afternoon to win.

# Questions

# Resources


AdaFruit GFX Library
https://learn.adafruit.com/adafruit-gfx-graphics-library/overview
565 Image Converter
http://rinkydinkelectronics.com/t_imageconverter565.php
Online Color Picker
https://ee-programming-notepad.blogspot.com/2016/10/16-bit-color-generator-picker.html

Contact Info for Paul Pagel:
• Email: pjpagel86@gmail.com

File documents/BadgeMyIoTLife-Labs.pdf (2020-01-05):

# Badge My IoT Life Lab Guide


ID | Item | Qty/Badge | Notes
U1 | ESP 32 DevkitC | 1 | should have 38 pins
U2 | 2.2" TFT LCD ILI9341 SPI | 1
| 18650 rechargeable battery | 1
BT1 | Battery holder | 1
| Custom PCB - v1.2 | 1
SW2-SW9 | Tactile momentary buttons | 8 | normally open
BZ1 | Mini speaker/transducer | 1 | passive, polarized
SW1 | SPDT slide switch | 1 | power on/off
RV1 | 1K trim pot | 1 | speaker volume, 500 – 2,000 Ohm will work fine
R10-R13 | 4K7 resistors - 1/4 watt | 4 | pullup resistors for direction buttons
R1-R3 | 100R resistors - 1/4 watt | 3 | current limiters for LEDs
R4 | 10M resistor - 1/4 watt | 1 | voltage divider for battery level
R5 | 3M3 resistor - 1/4 watt | 1 | voltage divider for battery level
D3-D5 | LEDs (1 red, 1 yellow, 1 green) | 3 | 5mm, any colors will work
C1 | 0.1uF ceramic capacitor | 1 | marked 104
| USB Battery Charger – TP4056 | 1
| Male and Female header pins | 1x40 m, 2x40 f | allows ESP32 & TFT to be removed, I2C/serial jumpers
| 3D printed hanger | 1 | allows badge to be worn with a lanyard


# Lab #1 :: Hello World!

1. Create a new project with a name like “Hello_Badge” for the NodeMCU-32S
2. In the setup() function, enter:
Serial.begin(9600);
Serial.println("Hello Badge");
3. Click the Upload (right arrow) icon:
4. Verify that it builds correctly and uploads to the board:
5. In Arduino IDE, select Tools -> Serial Monitor.
In PlatformIO, click the Serial Monitor icon.
6. Run the app again and verify that your “Hello Badge” message is shown in the Serial Monitor window:
7. Your serial begin parameter must match the Serial Monitor setting!
Try changing the speed param in the code to:
Serial.begin(115200);
In the Arduino IDE, this is selected from a
dropdown on the serial monitor window. In PlatformIO, open platformio.ini and enter: monitor_speed = 115200

# Lab #2 :: Hello, My Name Is

1. Click on Libraries and add “Adafruit GFX” and “Adafruit ILI9341”
2. Add the includes (try typing them to see the intellisense in action) #include <Adafruit_GFX.h>
#include <Adafruit_ILI9341.h>

3. Add the TFT constructor before the setup() function:
Adafruit_ILI9341 tft = Adafruit_ILI9341(15, 4, 23, 18, 2, 19);
4. Add the following inside your setup() function:
tft.begin();
tft.fillScreen(ILI9341_BLACK);
tft.setTextColor(ILI9341_WHITE);
tft.print(“Your Name");
5. Upload the sketch. You should see the screen go dark and display your name – though it may not look quite like you’d expect. We’ll fix that shortly.
6. Add the following font includes after the ILI9341 library include:
#include <Fonts/FreeSansBold24pt7b.h>

#include <Fonts/FreeSansBold9pt7b.h>

#include <Fonts/FreeSansOblique18pt7b.h>

7. In setup() , replace the statements after tft.begin() with:

tft.setRotation(3);

This will set the TFT rotation to landscape, like the badge.
8. Before setup(), add:

const char* my_name = “Your Name Here";
9. Add the following to setup(), after the existing statements: tft.setFont(&FreeSansBold24pt7b); tft.setTextColor(ILI9341_WHITE); tft.setCursor(50, 46);
tft.print("H E L L O");
tft.setFont(&FreeSansBold9pt7b); tft.setTextColor(ILI9341_WHITE); tft.setCursor(106, 68);
tft.print("my name is");
int16_t x1, y1;

uint16_t wd, ht;
tft.setFont(&FreeSansOblique18pt7b);
// Get the size of the displayed name using this font to center tft.getTextBounds(my_name, 10, 50, &x1, &y1, &wd, &ht); tft.setCursor(160 - (wd / 2), 120 + ht); tft.setTextColor(ILI9341_BLACK);
tft.print(my_name);
10. Upload the program. You should see something similar to:


If you get stuck, check out the esp32-badge-hello sketch: https://github.com/DigiTorus86/ESP32Badge/blob/master/hello-badge/esp32-badge-hello/esp32-badge-hello.ino (https://github.com/DigiTorus86/ESP32Badge/blob/master/hello-badge/esp32-badge-hello/esp32-badge-hello.ino)

# Lab #3 :: Add Your Picture

1. Take a selfie using your laptop camera or cellphone, or select some other image you’d like to use and open it in your image editing software.
2. Crop and/or scale the image to approximately 120 x 120 pixels.
3. Save the new image as a JPG or PNG file.
4. Convert the image to C using either an online utility or Python script. http://rinkydinkelectronics.com/t_imageconverter565.php
5. Copy the result file to your Hello_Badge sketch folder or create a new include file (tab) in your sketch and add the C image code to it.
6. Add the include below the others in your main file, adjusting the filename as needed: #include “mypicture.h”
7. Add the call to display your picture at the end of setup():
tft.drawRGBBitmap(0, 100, &mypicture, 120, 120);
8. Adjust the name display cursor x coordinate:
tft.setCursor(220 - (wd / 2), 120 + ht); tft.setTextColor(ILI9341_BLACK);
tft.print(my_name);
9. If you have a long name, you may want to just use your first name or break it into two different print() calls.
10. Upload the program. You should see something similar to:


If you get stuck, check out the esp32-badge-hello-pic sketch: https://github.com/DigiTorus86/ESP32Badge/tree/master/hello-badge/esp32-badge-hello-pic

# Lab #4 :: Adding LEDs and Buttons

1. Add the following at the end of setup():
pinMode(14, OUTPUT); // red
pinMode(12, OUTPUT); // yellow
pinMode(13, OUTPUT); // green
2. Inside loop(), add:
digitalWrite(14, HIGH);
digitalWrite(12, HIGH);
digitalWrite(13, HIGH);
delay(250);
digitalWrite(14, LOW);
digitalWrite(12, LOW);
digitalWrite(13, LOW);
delay(250);
3. Upload the program. The 3 badge LEDs should now be blinking on and off every quarter second.
4. Add the following at the end of setup():
pinMode(36, INPUT_PULLUP); // Up button
pinMode(39, INPUT_PULLUP); // Down button
5. Add the following at the start of loop():
static uint16_t delay_ms = 250;
if(digitalRead(36) == LOW) // up pressed
delay_ms = (delay_ms > 100 ? delay_ms - 100 : 10); if(digitalRead(39) == LOW) // down pressed
delay_ms = (delay_ms < 5000 ? delay_ms + 100 : 5000);
6. Change both delay(250) to:
delay(delay_ms);
7. Upload the program. The 3 badge LEDs should still be blinking on and off every quarter second.
8. Press the Up button on the badge. The LEDs should blink faster, eventually just appearing to stay on.
9. Press the Down button. The LEDs should blink slower.

# Lab #5 :: The Basic Bro

If you haven’t already done so, download the badge code repo from GitHub to your laptop: https://github.com/DigiTorus86/ESP32Badge
1. Load the esp32-badge-basic sketch into the IDE
2. Build it without making any changes. This will verify that you have the needed libraries in place.
3. Change the my_name/company values to whatever you want
4. Upload the sketch to your badge and verify that it loads and runs correctly.
5. Use the X and Y buttons to cycle through the badge display modes.
6. Make some customizations:
- Open HelloRotate.h and edit the message values. The wittier the better!
- Change the _COLOR_HEADER values in Hello.h and HelloRotate.h to your favorite colors.
7. Create a 320 x 240 graphic to replace the picture in gangster.h.
Follow the same steps as the previous lab for image conversion.
8. Upload and verify everything still works.

# Lab #6 :: QR Code Badge

1. Ensure your phone is charged and on the CodeMash WiFi.
2. Load the esp32-badge-qrcode sketch.
3. Enter the appropriate values for name, company, and WiFi in the main file: const char* my_name = "";
const char* company = "";
const char* ssid = "";
const char* password = "";
4. Optional: replace headshot.h with your 120x120-ish picture created in the previous lab. In drawBadge(), adjust the dimensions or name of the bitmap as needed: tft.drawRGBBitmap(0, 130, (uint16_t *)headshot, 111, 111);
5. Upload the app to your badge, and wait for the yellow LED to turn on, then off – indicating that the badge is connected to WiFi.
6. Press the B button to display the large QR code (smaller one may work, but is more subject to lighting, reflection, and camera issues.)
7. Use the camera or QR scan app on your phone to scan the QR code.
8. Use the button displayed in the webpage on your phone to turn the green LED on and off.
IDEA: Create a new version of the sketch with the QR code containing the URL for your personal or company website.

# Time & Weather Badge

1. Load the esp32-badge-time-weather sketch.
2. Enter the appropriate values for WiFi in the main file:
const char* ssid = "";
const char* password = "";
Upload sketch to verify that the badge is able to get on the WiFi and retrieve the current time and weather for Sandusky.
Optional: Follow the steps in the code to customize the city for the forecast API.

# Lab #7 :: BLE Remote Control

1. Talk to your partner(s) and decide who is going to be “peripheral” and who is going to be “central” for the first iteration. Everyone should get a chance to do both roles.

Peripheral is the badge acting as the controller (just like an Xbox™ controller) Central is the badge being controlled (like your Xbox™ console)

Execute instructions 2-4 on one of the following two slides depending on your role.

PERIPHERAL STEPS
2. Open the esp32-badge-ble-peripheral sketch and upload it to your badge.
3. The screen should look very similar to the hardware test app that was pre-loaded on your ESP32. However, there should be a 6-byte address line in orange at the bottom. ADDR: xx:xx:xx:xx:xx:xx
4. Copy the address to a piece of paper or show the screen to your central partner when they are ready to configure the central sketch. Include the colon separators.

CENTRAL STEPS
2. Open the esp32-badge-ble-central sketch.
3. Get the MAC address from your peripheral partner’s display and change the value of the address variable at the top of the sketch to match it:
String esp32_peripheral_address = “enter address here";
4. Upload the sketch to your badge.
5. The central badge should initially display list of detected BLE devices.
6. When/if it finds the configured address, it should pair – at which point the green light on both badges should come on. The yellow LEDs will pulse on send/receive data.
7. Start pushing puttons on the peripheral badge. The corresponding indicator on the central badge display should change accordingly.
8. Switch roles and repeat steps 2-7 until everyone has had a turn
with each role.

# Lab #8 :: WAV Player

1. Download and install the XT DAC Audio library (v4.2 or higher) https://www.xtronical.com/the-dacaudio-library-download-and-installation/
2. Open the esp32-badge-wav-play sketch from the hello-badge folder.
3. Upload to your badge.
4. Press the B button and verify you can hear the sound clip. You may need to rotate the trimpot counterclockwise to increase volume.
5. Download or record a WAV file for your badge.
6. Follow the steps from the previous slides to save the WAV file as an 8-bit 11KHz mono PCM sample.
7. Export the file to a C array using either the HxD app or the wav-pm8.py script and add it to your sketch folder.
8. Add the include directive for your sound file.
9. Add the XT_Wav_Class player declaration for this sample:
XT_Wav_Class mywav_play(mywav_wav);
10. Add the following to loop() after btnA_pressed = true: DacAudio.Play(&mywav_play);
11. Modify the while condition in loop():
while (audio_play.Playing || mywav_play.Playing)
12. Upload the sketch and verify the sound is played when
the A button is pressed.

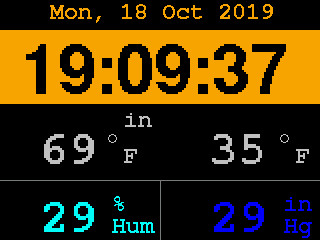
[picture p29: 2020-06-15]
images/TimeTemp-screen.jpg

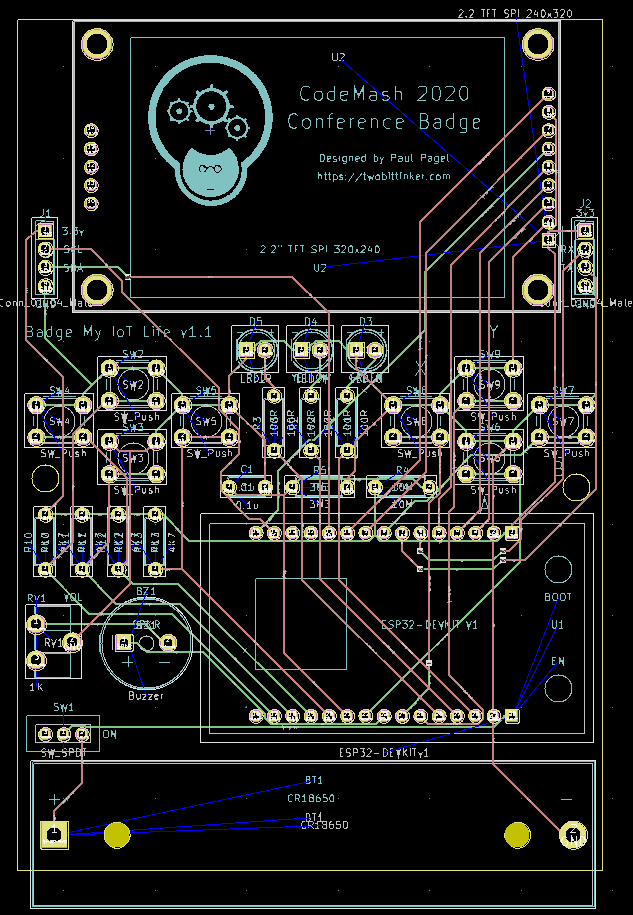
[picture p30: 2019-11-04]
images/PCB v1b.png

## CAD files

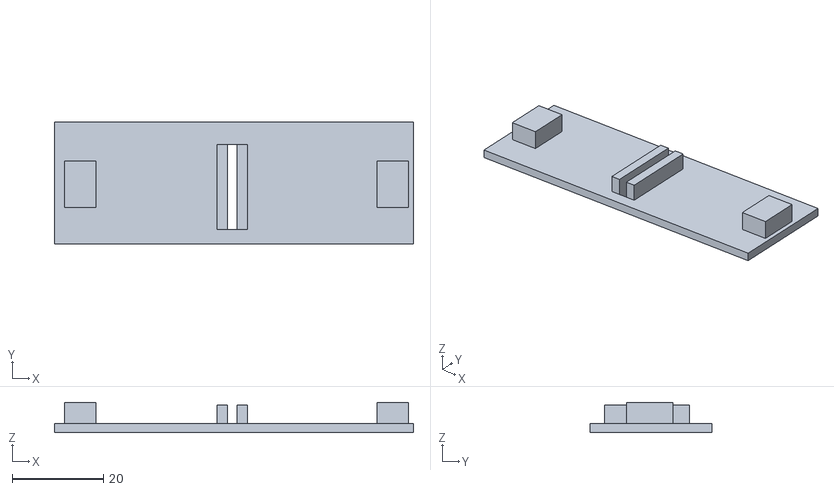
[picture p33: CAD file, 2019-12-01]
accessories-3d-print/kickstand/backplate.stl
78.7 x 26.7 x 6.60

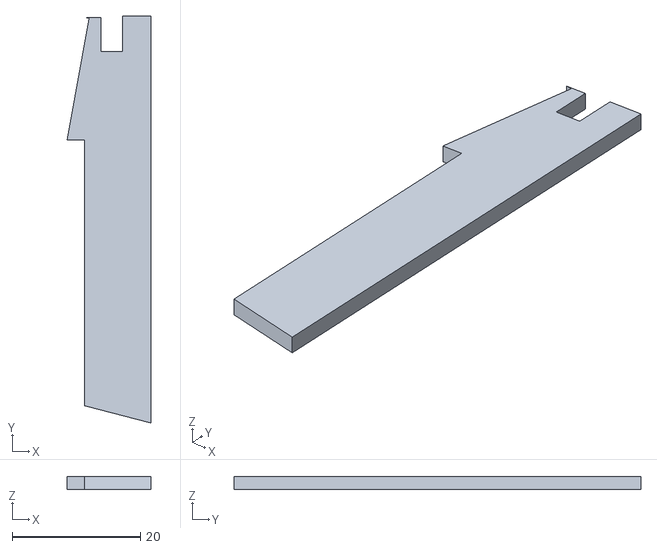
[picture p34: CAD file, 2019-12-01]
accessories-3d-print/kickstand/kickstand.stl
13.1 x 63.5 x 2.03

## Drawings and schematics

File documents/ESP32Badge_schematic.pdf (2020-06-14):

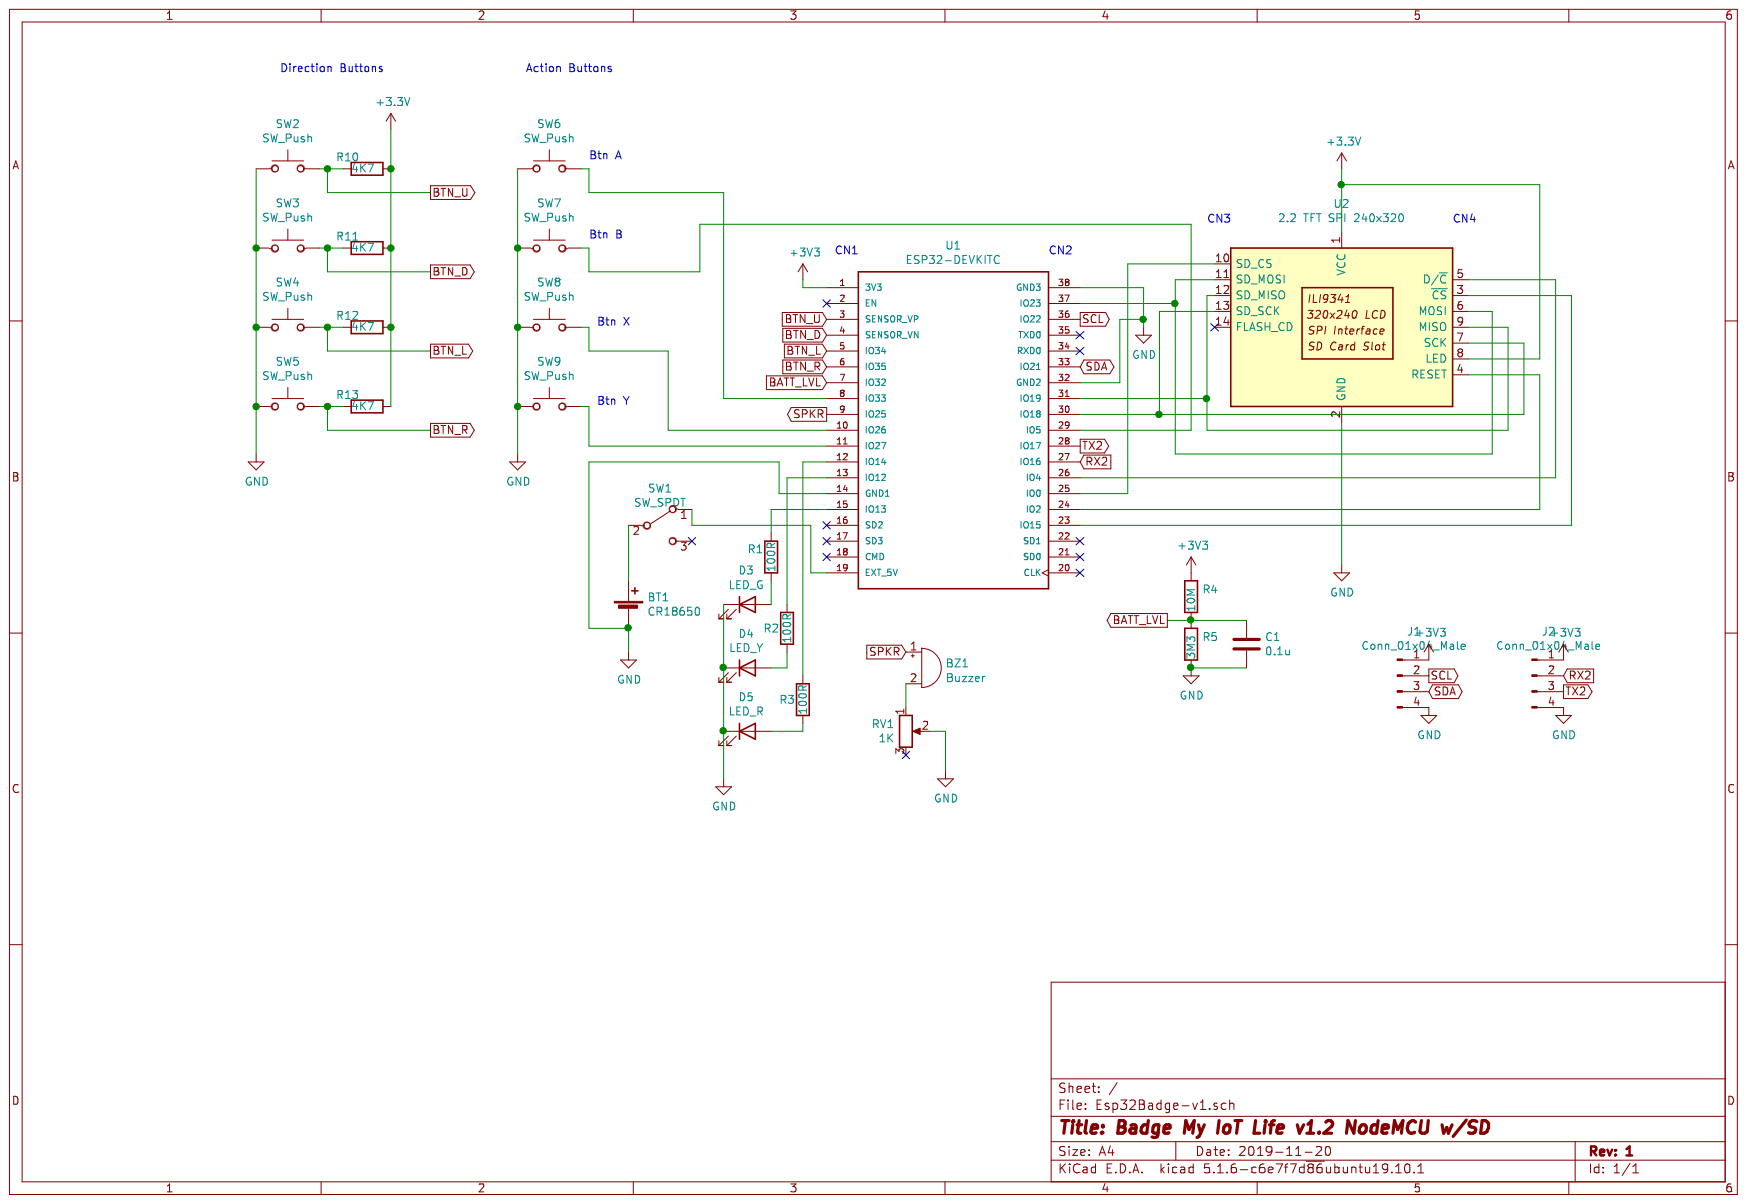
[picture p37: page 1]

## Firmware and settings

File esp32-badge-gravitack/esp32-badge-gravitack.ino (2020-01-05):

/***************************************************
ESP32 Badge - Gravitack game
An homage to the classic arcade console
by Paul Pagel

Requires:
 - ESP32 Badge

 Copyright (c) 2019 Paul Pagel
This is free software; see the license.txt file for more information.
There is no warranty; not even for merchantability or fitness for a particular purpose.
*****************************************************/

#include "esp32_badge.h"
#include "XT_DAC_Audio.h";
#include "Levels.h"
#include "Bitmaps.h"
#include "FireWav.h"
#include "RefuelWav.h"
#include "ExplosionWav.h"
#include "WarpWav.h"
#include "TickWav.h"

#define SHIP_SIZE    8
#define THRUST_SIZE  3 
#define SHOT_SPEED   8
#define MAX_SHOTS    4
#define MAX_GROUND  32
#define MAX_FUEL     8
#define MAX_TURRET   8
#define MAX_LIVES    6

#define PLAYER_FUEL_X 30
#define GAME_TOP   20 
#define FUEL_WD     8
#define FUEL_HT    16
#define INVALID_ITEM 999

enum game_state_type {
  STATE_TITLE,
  STATE_RULES,
  STATE_PLAYING,
  STATE_PAUSED,
  STATE_GAME_OVER
};

enum direction_type {
  DIR_UP = 1,
  DIR_DOWN = 2,
  DIR_LEFT = 3,
  DIR_RIGHT = 4
};

enum game_state_type game_state;

// constants used to speed up trig calculations
const double PId2  = PI / 2;
const double PId15 = PI / 1.5;
const double PIx15 = PI * 1.5;
const double PIx075 = PI * 0.75;

static bool btnA_pressed, btnB_pressed, btnX_pressed, btnY_pressed;
static bool btnB_pressed_prev;
static bool btnUp_pressed, btnDown_pressed, btnLeft_pressed, btnRight_pressed;
static bool spkr_on, led1_on, led2_on, led3_on;

uint8_t spkr_channel = 1;

static int    player_start_x, player_start_y;
static double player_ctr_x = SCREEN_WD / 2;
static double player_ctr_y = SCREEN_HT / 4;
static double player_rotation = PIx15;
static double player_speed_x;
static double player_speed_y;
static double player_fuel;
static int    player_lives;
static long   player_score;
static long   next_ship = 10000;
static double gravity = 0.02;
static int    level;
static int    level_delay = 10;

int ship_x[9];
int ship_y[9];
int shot_x[MAX_SHOTS];
int shot_y[MAX_SHOTS];
int shot_range[MAX_SHOTS];
double shot_speed_x[MAX_SHOTS];
double shot_speed_y[MAX_SHOTS];
int player_shot_range; // # of game loops new shots can exist

int ground_x[MAX_GROUND];
int ground_y[MAX_GROUND];
int ground_size = 0;  // # of ground line segments in the current level

int  fuel_x[MAX_FUEL];
int  fuel_y[MAX_FUEL];
bool fuel_active[MAX_FUEL];
int  fuel_count;    // # starting fuel packs in level
int  fuel_remaining;  // # remaining fuel packs in level

int  turret_x[MAX_TURRET];
int  turret_y[MAX_TURRET];
int  turret_dir[MAX_TURRET];
bool turret_active[MAX_TURRET];
int  turret_shot_x[MAX_TURRET];
int  turret_shot_y[MAX_TURRET];
int  turret_shot_range[MAX_TURRET];
double turret_shot_speed_x[MAX_TURRET];
double turret_shot_speed_y[MAX_TURRET];
int  turret_range;    // # of game loops new turret shots can exist
int  turret_count;    // # starting turrets in level
int  turret_remaining;  // # remaining turrets in level

int turret_offset_x[4] = { 10, 10,-10, 20};
int turret_offset_y[4] = {-10, 10, 10, 10};

// Sound FX
XT_DAC_Audio_Class DacAudio(SPKR, 0);  // main audio object
XT_Wav_Class fire_play(fire_wav);     
XT_Wav_Class refuel_play(refuel_wav); 
XT_Wav_Class explosion_play(explosion_wav); 
XT_Wav_Class warp_play(warp_wav);
XT_Wav_Class tick_play(tick_wav);

Adafruit_ILI9341 tft = Adafruit_ILI9341(TFT_CS, TFT_DC, TFT_MOSI, TFT_CLK, TFT_RST, TFT_MISO);

/*
 *  Initialize hardware, peripherals, and libraries
 */
void setup() 
{
  Serial.begin(115200);
  Serial.println("ESP32 Badge - Gravitack"); 
  delay(100);

  // not needed since we'll be using digital audio, which does not share nicely with LEDC
  //ledcSetup(spkr_channel, 12000, 8);  // 12 kHz max, 8 bit resolution
  //ledcAttachPin(SPKR, spkr_channel);

  // Set up user input pins
  // Pins 24, 35, 36, & 39 on ESP32 do NOT have internal pullups, so need 4k7 physical resistors for these
  pinMode(BTN_UP, INPUT_PULLUP);
  pinMode(BTN_DOWN, INPUT_PULLUP);   
  pinMode(BTN_LEFT, INPUT_PULLUP);
  pinMode(BTN_RIGHT, INPUT_PULLUP);
  pinMode(BTN_A, INPUT_PULLUP);
  pinMode(BTN_B, INPUT_PULLUP);
  pinMode(BTN_X, INPUT_PULLUP);
  pinMode(BTN_Y, INPUT_PULLUP);

  // Set up the speaker and LED output pins
  pinMode(SPKR, OUTPUT);
  pinMode(LED_1, OUTPUT);
  pinMode(LED_2, OUTPUT);
  pinMode(LED_3, OUTPUT);

  delay(100);
 
  tft.begin();
  tft.setRotation(SCREEN_ROT);

  drawTitleScreen();
}

/*
 * Draws the game title/splash screen
 */
void drawTitleScreen()
{
  tft.fillScreen(ILI9341_BLACK);

  tft.drawRGBBitmap(20, 60, (uint16_t *)gravitack_title, 279, 77);
  
  tft.setTextSize(2);
  tft.setTextColor(ILI9341_WHITE);
  tft.setCursor(40, 200);
  tft.print("[X] RULES, [Y] START");

  game_state = STATE_TITLE;
}

/*
 * Draws the game instructions screen
 */
void drawRulesScreen()
{
  tft.fillScreen(ILI9341_BLACK);
  
  tft.setTextSize(2);
  tft.setTextColor(ILI9341_WHITE);
  tft.setCursor(50, 0);
  tft.print("CONTROLS & SCORING");

  tft.drawLine(0, 25, 320, 25, ILI9341_GREEN);

  tft.setTextColor(ILI9341_DARKGREY);
  tft.setTextSize(2);
  tft.setCursor(10, 40);
  tft.print("Thrust: [A]");

  tft.setCursor(190, 40);
  tft.print("Pause: [X]");
  
  tft.setCursor(10, 60);
  tft.print("Fire:   [B]");
  
  
  tft.drawRect(24, 100, FUEL_WD, FUEL_HT, ILI9341_CYAN);
  
  tft.setCursor(50, 100);
  tft.print("200 pts");

  tft.setTextSize(1);
  tft.setCursor(160, 100);
  tft.print("Touch fuel packs with your");
  tft.setCursor(160, 110);
  tft.print("ship to pick them up");
  
  drawTurret(15, 140, 1);

  tft.setTextSize(2);
  tft.setCursor(50, 135);
  tft.print("500 pts"); 

  tft.setTextSize(1);
  tft.setCursor(160, 145);
  tft.print("Shoot all turrets");
  
  tft.setCursor(50, 165);
  tft.print("Pick up all fuel packs and destroy all");
  tft.setCursor(50, 175);
  tft.print("turrets to advance to the next level.");
  tft.setCursor(50, 190);
  tft.print("** Free ship every 10,000 points **");

  tft.drawLine(0, 210, 320, 210, ILI9341_GREEN);

  tft.setTextColor(ILI9341_WHITE);
  tft.setTextSize(2);
  tft.setCursor(60, 220);
  tft.print("PRESS [Y] TO START");
  
  game_state = STATE_RULES;
}

/*
 * Initializes the game variables and draws the main gameplay screen
 */
void startGame(int startLevel)
{
  tft.fillScreen(ILI9341_BLACK);

  level = startLevel;
  player_score = 0;
  player_lives = 4;
  player_shot_range = 100;
  next_ship = 10000;
  turret_range = 10;

  loadLevel(level);
  drawHeader();
  drawGround();
  drawShip(player_ctr_x, player_ctr_y, player_rotation, false);

  game_state = STATE_PLAYING;
}

/*
 * Draws a Paused message on the screen
 */
void drawPaused()
{
  tft.fillRect(110, 20, 112, 20, ILI9341_BLACK);
  tft.setTextSize(1);
  tft.setTextColor(ILI9341_RED);
  tft.setCursor(110, 20);
  tft.print("** PAUSED **");
  delay(200);
  
  game_state = STATE_PAUSED;
}

/*
 * Erases the Paused message
 */
void erasePaused()
{
  tft.fillRect(110, 20, 112, 20, ILI9341_BLACK);
  delay(200);
  
  game_state = STATE_PLAYING;
}

/*
 * Draws the Game Over screen
 */
void drawGameOver()
{
  drawHeader();
  drawGround();
  tft.fillRect (80, 70, 160, 55, ILI9341_BLACK);  // clear msg area
  tft.drawRect (80, 70, 160, 55, ILI9341_YELLOW); // border
  
  tft.setTextSize(2);
  tft.setTextColor(ILI9341_WHITE);
  tft.setCursor(105, 80);
  tft.print("GAME OVER");

  tft.setTextSize(1);
  tft.setTextColor(ILI9341_WHITE);
  tft.setCursor(105, 110);
  tft.print("PRESS [Y] TO START");

  game_state = STATE_GAME_OVER;
}

void wipeGameArea()
{
  DacAudio.Play(&warp_play);
  for (int i = 0; i <= 110; i++)
  {
    tft.drawRect(110 - i, 130 - i, i * 2 + 100, i * 2, ILI9341_WHITE);
    DacAudio.FillBuffer(); 
  }
  DacAudio.FillBuffer(); 
  for (int i = 0; i <= 110; i++)
  {
    tft.drawRect(110 - i, 130 - i, i * 2 + 100, i * 2, ILI9341_BLACK);
    DacAudio.FillBuffer(); 
  }
}

/*
 * Plays the player shot sound
 */
void playShot()
{
  DacAudio.Play(&fire_play);
}

/*
 * Draws and plays an explosion sound for a turret or the player ship
 */
void drawExplosion(int x, int y, int maxRadius)
{
  DacAudio.Play(&explosion_play);
  for (int i = 1; i <= maxRadius; i++)
  {
    tft.drawCircle(x, y, i, ILI9341_YELLOW);
    DacAudio.FillBuffer(); 
    delay(10);
  }
  for (int i = 1; i <= maxRadius; i++)
  {
    tft.drawCircle(x, y, i, ILI9341_BLACK);
    DacAudio.FillBuffer(); 
    delay(10);
  }
}

/* 
 *  Plays the fuel pickup sound 
 */
void playFuelSound()
{
  DacAudio.Play(&refuel_play);
}

/*
 * Initializes the player and turret shots to inactive
 */
void initShots()
{
  for (int i = 0; i < MAX_SHOTS; i++)
  {
    if (shot_range[i])  // erase old active shot
      tft.drawRect(shot_x[i], shot_y[i], 2, 2, ILI9341_BLACK);
    
    shot_range[i] = 0;
  }

  for (int i = 0; i < MAX_TURRET; i++)
  {
    if (turret_shot_range[i])  // erase old active turret shot
      tft.drawRect(turret_shot_x[i], turret_shot_y[i], 2, 2, ILI9341_BLACK);
    
    turret_shot_range[i] = 0;
  }
}

/*
 * Initializes game level (ground, fuel packs, turrets) from the level data parameter
 */
void loadLevelData(const int levelData[])
{
  // Load the ground segment data
  for (int i = 0; i < MAX_GROUND; i++)
   {
     if (levelData[i * 2] < 999)
     {
      ground_x[i] = levelData[i * 2];
      ground_y[i] = levelData[i * 2 + 1];
      ground_size = i;
     }
   }
   
   // Load the fuel pack location data
   int fuel_start = MAX_GROUND * 2;
   fuel_count = 0;
   
   for (int i = 0; i < MAX_FUEL; i++)
   {
     if (levelData[fuel_start + i * 2] < 999)
     {
      fuel_x[i] = levelData[fuel_start + i * 2];
      fuel_y[i] = levelData[fuel_start + i * 2 + 1];
      fuel_active[i] = true;
      fuel_count += 1;
     }
     else
     {
       fuel_active[i] = false;
     }
   }
   fuel_remaining = fuel_count;
  
   // Load the enemy turret location data
   int turret_start = fuel_start + MAX_FUEL * 2;
   turret_count = 0;
   
   for (int i = 0; i < MAX_TURRET; i++)
   {
     if (levelData[turret_start + i * 3] < 999)
     {
      turret_x[i] = levelData[turret_start + i * 3];
      turret_y[i] = levelData[turret_start + i * 3 + 1];
      turret_dir[i] = levelData[turret_start + i * 3 + 2];
      turret_active[i] = true;
      turret_count += 1;
     }
     else
     {
       turret_active[i] = false;
     }
   }
   turret_remaining = turret_count;
   
   // Load the miscellanous player/level data
   int misc_start = turret_start + MAX_TURRET * 3;
   
   player_start_x = levelData[misc_start];
   player_start_y = levelData[misc_start + 1];
   level_delay = levelData[misc_start + 2];
   
   startPlayer();
}

/*
 * Initializes game level (ground, fuel packs, turrets) based on the level parameter
 */
void loadLevel(int lvl)
{
  int level_map = lvl;
  while (level_map > MAX_LEVEL)
  {
    level_map -= MAX_LEVEL;
  }
  
  switch(level_map)
  {
  case 1: loadLevelData((int *)Level_01);
    break;
  case 2: loadLevelData((int *)Level_02);
    break;
  case 3: loadLevelData((int *)Level_03);
    break;
  case 4: loadLevelData((int *)Level_04);
    break;
  case 5: loadLevelData((int *)Level_05);
    break;
  case 6: loadLevelData((int *)Level_06);
    break;
  default:  loadLevelData((int *)Level_01);
  }
  
  tft.fillRect(0, 10, 320, 240, ILI9341_BLACK);
}

/*
 * Draws the ground segments for the current level
 */
void drawGround()
{
  for (int i = 0; i < ground_size; i++)
  {
  if (ground_x[i] < INVALID_ITEM && ground_x[i+1] < INVALID_ITEM)
  {
    tft.drawLine(ground_x[i], ground_y[i], ground_x[i+1], ground_y[i+1], ILI9341_GREEN);
  }
  }
}

/*
 * Draws the game header at the top of the screen (fuel, lives, score)
 */
void drawHeader()
{
  tft.setTextSize(1);
  tft.setTextColor(ILI9341_WHITE);
  
  tft.setCursor(0, 1);
  tft.print("FUEL");
  drawPlayerFuel();

  drawPlayerLives();

  tft.setCursor(240, 0);
  tft.print("SCORE: 000000");
  changePlayerScore(0);  
}

/*
 * Draws the player fuel bar
 */
void drawPlayerFuel()
{
  tft.drawRect(PLAYER_FUEL_X - 1, 0, 103, 10, ILI9341_WHITE);
  tft.fillRect(PLAYER_FUEL_X, 1, player_fuel, 8, ILI9341_CYAN);
}

/*
 * Changes the player fuel by the given amount and redraws the fuel bar in the game header
 */
void changePlayerFuel(int changeAmt)
{
  if (changeAmt < 0)
  {
    tft.fillRect(PLAYER_FUEL_X + player_fuel, 1, changeAmt, 8, ILI9341_BLACK); 
    player_fuel += changeAmt;
    return;
  }

  // avoid going over fuel limit
  int chg = changeAmt;
  if (chg + player_fuel > 100)
    chg = 100 - player_fuel;

  tft.fillRect(PLAYER_FUEL_X + player_fuel, 1, chg, 8, ILI9341_CYAN); 
  player_fuel += chg;
  return;
}

/*
 * Changes and displays the player score and awards any free ships
 */
void changePlayerScore(int changeAmt)
{
  player_score += changeAmt;

  tft.fillRect(280,0, 40, 10, ILI9341_BLACK); // erase prev score
  tft.setTextColor(ILI9341_WHITE);
  tft.setCursor(280, 0);
  tft.print(player_score);
  
  if (changeAmt > 0 && player_score >= next_ship)
  {
    player_lives += 1;
    next_ship += 10000;
    drawPlayerLives();
  }
}

/*
 * Draws the player lives remaining in the game header
 */
void drawPlayerLives()
{
    int ctr_x, ctr_y;
    int x[5], y[5];
    
    for (int i = 0; i < MAX_LIVES; i++)
    {
      if (i < player_lives)
      {
        ctr_x = 150 + i * 16;
        ctr_y = 9;
        
        // nose of ship
        x[0] = ctr_x + cos(PIx15) * SHIP_SIZE;
        y[0] = ctr_y + sin(PIx15) * SHIP_SIZE;
        // left wingtip
        x[1] = ctr_x + cos(PIx15 - PId15) * SHIP_SIZE;
        y[1] = ctr_y + sin(PIx15 - PId15) * SHIP_SIZE;
        //center point
        x[2] = ctr_x;
        y[2] = ctr_y;
        // right wingtip
        x[3] = ctr_x + cos(PIx15 + PId15) * SHIP_SIZE;
        y[3] = ctr_y + sin(PIx15 + PId15) * SHIP_SIZE;
        // nose of ship
        x[4] = x[0];
        y[4] = y[0];
  
        // connect ship vertices
        for(int i = 0; i < 4; i++)
        {
          tft.drawLine(x[i], y[i], x[i+1], y[i+1], ILI9341_BLUE);
        }
      }
      else
      {
        // blank out ship space
        tft.fillRect(ctr_x - SHIP_SIZE, 0, 16, 16, ILI9341_BLACK);
      }
    }
}

/*
 * Draws the fuel packs on the game screen
 */
void drawFuelPacks()
{
  for (int i = 0; i < fuel_count; i++)
  {
    if (fuel_active[i])
    {
      drawFuelPack(fuel_x[i], fuel_y[i]);
    }
  }
}

/*
 * Draws a fuel pack at the given x,y coordinate (top left corner)
 */
void drawFuelPack(int x, int y)
{
  tft.drawRect(x, y, FUEL_WD, FUEL_HT, ILI9341_CYAN);
}

/*
 * Erases a fuel pack at the given x,y coordinate (top left corner)
 */
void eraseFuelPack(int x, int y)
{
  tft.drawRect(x, y, FUEL_WD, FUEL_HT, ILI9341_BLACK);
}

/*
 * Draws all turrets and randomly shoots at the player based on the shotRate
 */
void drawTurrets(int shotRate)
{
  int x, y;
  
  for (int i = 0; i < turret_count; i++)
  {
    if (turret_active[i])
    {
      drawTurret(turret_x[i], turret_y[i], turret_dir[i]);
      
      if (shotRate > random(100))
      {
        // try to shoot (from tip of turret)
        x = turret_x[i] + turret_offset_x[turret_dir[i] - 1];
        y = turret_y[i] + turret_offset_y[turret_dir[i] - 1];
        createTurretShot(x, y);
      }
    }
  }
}

/*
 * Draws a turret at the given x,y coordinates
 */
void drawTurret(int x, int y, int direction)
{
  switch(direction)
  {
  case DIR_UP: 
    tft.drawRect(x, y, 20, 10, ILI9341_RED);
    tft.drawRect(x + 5, y - 10, 10, 10, ILI9341_RED);
    break;
  case DIR_DOWN:
    tft.drawRect(x, y, 20, 10, ILI9341_RED);
    tft.drawRect(x + 5, y + 10, 10, 10, ILI9341_RED);
    break;
  case DIR_LEFT:
    tft.drawRect(x, y, 10, 20, ILI9341_RED);
    tft.drawRect(x - 10, y + 5, 10, 10, ILI9341_RED);
    break;
  case DIR_RIGHT:
    tft.drawRect(x, y, 10, 20, ILI9341_RED);
    tft.drawRect(x + 10, y + 5, 10, 10, ILI9341_RED);
    break;
  default:
    tft.drawRect(x, y, 20, 20, ILI9341_RED); // headless
  }
}

/*
 * Erases a turret at the given x,y coordinates
 */
void eraseTurret(int x, int y, int direction)
{
  switch(direction)
  {
  case DIR_UP: 
    tft.drawRect(x, y, 20, 10, ILI9341_BLACK);
    tft.drawRect(x + 5, y - 10, 10, 10, ILI9341_BLACK);
    break;
  case DIR_DOWN:
    tft.drawRect(x, y, 20, 10, ILI9341_BLACK);
    tft.drawRect(x + 5, y + 10, 10, 10, ILI9341_BLACK);
    break;
  case DIR_LEFT:
    tft.drawRect(x, y, 10, 20, ILI9341_BLACK);
    tft.drawRect(x - 10, y + 5, 10, 10, ILI9341_BLACK);
    break;
  case DIR_RIGHT:
    tft.drawRect(x, y, 10, 20, ILI9341_BLACK);
    tft.drawRect(x + 10, y + 5, 10, 10, ILI9341_BLACK);
    break;
  default:
    tft.drawRect(x, y, 20, 20, ILI9341_BLACK); // headless
  }
}
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
void loop() 
{
  if(digitalRead(BTN_UP) == LOW)
  {
    btnUp_pressed = true;
  }
  else
  {
    btnUp_pressed = false;
  }

  if(digitalRead(BTN_DOWN) == LOW)
  {
    btnDown_pressed = true;
  }
  else
  {
    btnDown_pressed = false;
  }

  if(digitalRead(BTN_LEFT) == LOW)
  {
    btnLeft_pressed = true;
  }
  else
  {
    btnLeft_pressed = false;
  }

  if(digitalRead(BTN_RIGHT) == LOW)
  {
    btnRight_pressed = true;
  }
  else
  {
    btnRight_pressed = false;
  }
  
  
  if(digitalRead(BTN_X) == LOW)
  {
    btnX_pressed = true;
  }
  else
  {
    btnX_pressed = false;
  }

  if(digitalRead(BTN_Y) == LOW)
  {
    btnY_pressed = true;
  }
  else
  {
    btnY_pressed = false;
  }

  if(digitalRead(BTN_A) == LOW)
  {
    btnA_pressed = true; 
  }
  else
  {
    btnA_pressed = false;
  }
  
  if(digitalRead(BTN_B) == LOW)
  {
    btnB_pressed = true; 
  }
  else
  {
    btnB_pressed = false;
  }

  switch(game_state)
  {
    case STATE_TITLE:
      handleTitle(); 
      break;
    case STATE_RULES:
      handleRules();
      break;
    case STATE_PLAYING:
      handlePlaying();
      break;
    case STATE_PAUSED:
      handlePaused(); 
      break;
    case STATE_GAME_OVER:
      handleGameOver(); 
      break;
    
  }

  DacAudio.FillBuffer(); // load data for any pending audio samples
  btnB_pressed_prev = btnB_pressed;  // used to prevent double firing
  delay(level_delay);
}

/*
 * Handles the STATE_TITLE game state logic 
 */
void handleTitle()
{
  if (btnX_pressed)
  {
    drawRulesScreen();
    return;
  }

  if (btnY_pressed)
  {
    startGame(1);
    return;
  }

  // secret start level hack
  if (btnA_pressed)
  {
    //left = bit 0, up = bit 1, down = bit 2, righ = bit 3
    int startLevel = (btnLeft_pressed ? 1 : 0) + (btnUp_pressed ? 2 : 0) + (btnDown_pressed ? 4 : 0) + (btnRight_pressed ? 8 : 0); 
    startGame(startLevel);
  }
}

/*
 * Handles the STATE_RULES game state logic
 */
void handleRules()
{
  if (btnY_pressed)
  {
    startGame(1);
  }
}

/*
 * Handles the STATE_PLAYING game state logic
 */
void handlePlaying()
{
  // player controls logic
  if (btnX_pressed)
  {
    drawPaused();
    return;
  }
  
  if (btnLeft_pressed)
  {
    player_rotation -= 0.1;
  }

  if (btnRight_pressed)
  {
    player_rotation += 0.1;
  }
  
  player_speed_y += gravity;

  if (btnA_pressed)
  {
    if (player_fuel > 0)
    {
      player_speed_x += sin(player_rotation + PId2) / 8;
      player_speed_y -= cos(player_rotation + PId2) / 8;
      changePlayerFuel(-1);
    }
  }

  player_ctr_x += player_speed_x;
  player_ctr_y += player_speed_y;

  // screen bounds checking
  if ((player_ctr_x > SCREEN_WD - SHIP_SIZE && player_speed_x > 0) || 
      (player_ctr_x < SHIP_SIZE && player_speed_x < 0))
  {
    player_speed_x = -player_speed_x;
    player_ctr_x += player_speed_x;
  }

  if (((player_ctr_y > (SCREEN_HT - SHIP_SIZE)) && (player_speed_y > 0)) || 
      (player_ctr_y <  20 && (player_speed_y < 0)))
  {
    player_speed_y = -player_speed_y;
    player_ctr_y += player_speed_y;
  }

  if (btnB_pressed && !btnB_pressed_prev)
  {
    createPlayerShot(player_ctr_x, player_ctr_y, player_rotation);
  }

  // game object hit detection and updates/animation
  drawGround();
  drawFuelPacks();
  drawTurrets(2);
  moveTurretShots();
  if (game_state != STATE_PLAYING)  // in case player died
    return;
    
  if (checkFuelHit(player_ctr_x, player_ctr_y, SHIP_SIZE) >= 0)
  {
    changePlayerScore(200);
    changePlayerFuel(50); 
    fuel_remaining -= 1;
  }

  // check the ship vertices for ground collision
  if (hitsGround(player_ctr_x, player_ctr_y, SHIP_SIZE - 2))
  {
    killPlayer();
    return;
  }

  // check the ship vertices for ground collision
  // this is more accurate, though slower - especially with more ground segments
  /*
  for(int i = 0; i < 4; i++)
  {
    if (hitsGround(ship_x[i], ship_y[i], 1))
    {
      killPlayer();
      return;
    }
  }
  */
  
  
  eraseShip();
  drawShip(player_ctr_x, player_ctr_y, player_rotation, btnA_pressed && player_fuel > 0);

  movePlayerShots();

  if (turret_remaining == 0 && fuel_remaining == 0)
  {
    advanceLevel();
  }
}

/*
 * Handles the STATE_PAUSED game state logic
 */
void handlePaused()
{
  if (btnX_pressed)
  {
   erasePaused();
  }
}

/*
 * Handles the STATE_GAME_OVER game state logic
 */
void handleGameOver()
{
  if (btnY_pressed)
  {
    drawTitleScreen();
  }
}

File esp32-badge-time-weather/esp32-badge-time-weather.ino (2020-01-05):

/***************************************************
ESP32 Badge Time and Weather Display

Requires:
 - DS3231 Real Time Clock breakout
 - BME280 Temperature, pressure, & humidity breakout
 - WiFi network and credentials

 Will operate in a degraded mode if any of the requirements are not available.

 Controls:
 - X/Y:         Cycle through display modes
 - A:           Enter / commit set time
 - Left/Right:  Move selection field
 - Up/Down:     Increase/decrease selection value

Copyright (c) 2019 Paul Pagel
This is free software; see the license.txt file for more information.
There is no warranty; not even for merchantability or fitness for a particular purpose.
*****************************************************/

#include <Wire.h>
#include <SPI.h>
#include <Adafruit_GFX.h>
#include <Adafruit_ILI9341.h>
#include <Fonts/FreeMonoBold12pt7b.h> 
#include <Fonts/FreeSansBold18pt7b.h> 
#include <WiFi.h>
#include <HTTPClient.h>
#include <ArduinoJson.h>  // ArduinoJson by Benoit Blanchon
#include "time.h"
#include "esp32_badge.h"
#include "DS3231_RTC.h"
#include "SparkFunBME280.h"
#include "TFT_Helper.h"
#include "icons.h"

#define BADGE_WIFI_MODE  WIFI_MODE_AP // use WIFI_MODE_STA (station) for home WiFi, WIFI_MODE_AP (access point) when using mobile hotspot

const char*    ssid     = ""; // TODO: add your network ID here 
const char*    password = ""; // TODO: add your network password here 

/*  To customize: 
 *   1.  Go to https://www.weather.gov/documentation/services-web-api
 *   2.  Enter your zipcode and click the Go button
 *   3.  Copy the lat/long values from the resulting URL, i.e. lat=41.40137000000004&lon=-82.70880605999997
 *       and past them into this URL:  https://api.weather.gov/points/<lat>,<lon>
 *       example for Sandusky, OH:  https://api.weather.gov/points/41.40137000000004,-82.70880605999997
 *   4.  Copy the value of the properties->forecast node to the forecast_api_url assignment below:      
 */   
const char*    forecast_api_url = "https://api.weather.gov/gridpoints/CLE/48,56/forecast ";  // TODO: change this for your city
//const char*    forecast_api_url = "https://api.weather.gov/gridpoints/CLE/19,62/forecast?units=us";  // Perrysburg, OH

#define FORECAST_REFRESH_MS       3600000  // 1 hr
#define BME280_I2C_ADDR           0X76     // default address for BME280 is 0x77, mine was set to 0x76

// Display element color settings
#define COLOR_SCREEN_BGD          ILI9341_BLACK
#define COLOR_DATE                ILI9341_ORANGE
#define COLOR_TIME                ILI9341_BLACK
#define COLOR_TIME_BGD            ILI9341_ORANGE
#define COLOR_TIME_EDIT           ILI9341_BLUE
#define COLOR_SENSOR_LINES        ILI9341_DARKGREY
#define COLOR_SENSOR_TEMP         ILI9341_LIGHTGREY
#define COLOR_SENSOR_HUMID        ILI9341_CYAN
#define COLOR_SENSOR_PRESSURE     ILI9341_BLUE
#define COLOR_FORECAST_TEMP       ILI9341_GREEN
#define COLOR_FORECAST_TITLE      ILI9341_BLACK
#define COLOR_FORECAST_TITLE_BGD  ILI9341_GREEN
#define COLOR_FORECAST_BODY       ILI9341_DARKGREY

#define SCREEN_ROWS_MONO12       9
#define SCREEN_COLS_MONO12      22

// Calculates the screen X position for the given time digit 
// digit index values:  0 = h1, 1=h2, 2=m1, 3=m2, 4=s1, 5=s2
#define TIME_DIGIT_X(digit)       (20 + (digit) * 38 + ((digit) > 1 ? 20 : 0) + ((digit) > 3 ? 20 : 0))

bool getNtpTime();
bool getForecast();


const uint16_t net_connect_timeout_sec = 10;
const char*   ntp_server = "pool.ntp.org";
// TODO: change this if you are not in the Eastern US time zone
const long    gmt_offset_sec = -18000;      // EST GMT-5 * 3600 seconds per hour
const int     daylight_offset_sec = -14400; // EDT GMT-4 * 3600 seconds per hour

bool wifi_available, ds3231_available, bme280_available;  

#define DISPLAY_MODE_CNT  4
enum display_mode_type 
{
  MODE_TIME_AND_SENSOR,
  MODE_DAY_FORECAST,
  MODE_TOMORROW_FORECAST,
  MODE_SET_TIME
};
enum display_mode_type display_mode, prev_display_mode;

struct ds3231_time_t curr_time;
DS3231_RTC rtc = DS3231_RTC();
BME280 sensor;

// Use https://arduinojson.org/v5/assistant/ to find appropriate JSON memory size
StaticJsonDocument<15000> json_doc; // holds the forecast from the weather API
unsigned long forecast_age_ms;    // # milliseconds elapsed since the forecast was retrieved
bool forecast_loaded = false;

uint8_t curr_time_digits[6];
uint8_t prev_time_digits[6];
uint8_t prev_day;

int16_t curr_temp_f, curr_temp_c, curr_humid, curr_pressure, forecast_temp_f;
int16_t prev_temp_f, prev_temp_c, prev_humid, prev_pressure, prev_forecast_temp_f;

bool btnA_pressed, btnB_pressed, btnX_pressed, btnY_pressed;
bool btnUp_pressed, btnDown_pressed, btnLeft_pressed, btnRight_pressed;
bool btnUp_released, btnDown_released, btnLeft_released, btnRight_released;
bool spkr_on, led1_on, led2_on, led3_on;

uint8_t spkr_channel = 1;

Adafruit_ILI9341 tft = Adafruit_ILI9341(TFT_CS, TFT_DC, TFT_MOSI, TFT_CLK, TFT_RST, TFT_MISO);

void setup() 
{
  Serial.begin(115200);
  Serial.println("ESP32 Badge Time and Weather"); 
  delay(100);

  ledcSetup(spkr_channel, 12000, 8);  // 12 kHz max, 8 bit resolution
  ledcAttachPin(SPKR, spkr_channel);

  // Set up user input pins
  pinMode(BTN_UP, INPUT_PULLUP);
  pinMode(BTN_DOWN, INPUT_PULLUP);   
  pinMode(BTN_LEFT, INPUT_PULLUP);
  pinMode(BTN_RIGHT, INPUT_PULLUP);
  pinMode(BTN_A, INPUT_PULLUP);
  pinMode(BTN_B, INPUT_PULLUP);
  pinMode(BTN_X, INPUT_PULLUP);
  pinMode(BTN_Y, INPUT_PULLUP);

  // Set up the speaker and LED output pins
  pinMode(SPKR, OUTPUT);
  pinMode(LED_1, OUTPUT);
  pinMode(LED_2, OUTPUT);
  pinMode(LED_3, OUTPUT);

  delay(100);
  
  // Set up the TFT screen
  tft.begin();
  tft.setRotation(SCREEN_ROT);

  Wire.begin();  // fire up I2C

  // Initialize the BME280 sensor
  sensor.setI2CAddress(BME280_I2C_ADDR);    
  bme280_available = sensor.beginI2C();
  if (bme280_available == false)
  {
    Serial.println("The BME280 sensor did not respond. Check I2C wiring and address jumpers.");
    digitalWrite(LED_1, HIGH);  // redlight!
  }

  // Check the DS3231 RTC
  ds3231_available = rtc.readDS3231time(&curr_time);
  if (ds3231_available == false)
  {
    Serial.println("The DS3231 RTC did not respond. Check I2C wiring and address jumpers.");
    digitalWrite(LED_1, HIGH);  // redlight!
  }

  // Try to get the current local time from NTP server
  if (strlen(ssid) > 0)
  {
    wifi_available = getNtpTime();
    if (wifi_available)
    {
      getForecast();
    }
    else
    {
      Serial.println("Unable to get Network Time. Check network SSID and password.");
      digitalWrite(LED_1, HIGH);  // redlight!
    }
  }
  else
  {
    Serial.println("No network SSID specified.");
    wifi_available = false;
  }
 
  
  display_mode = MODE_TIME_AND_SENSOR;
  beginTimeAndSensor();
}
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

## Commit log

2019-11-04 added images and gerbers
    [Esp32Badge-v1-B_Cu.gbr, Esp32Badge-v1-B_Mask.gbr, Esp32Badge-v1-B_Paste.gbr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]
2019-11-15 fixed serial header RX/TX connections
    [Esp32Badge-v1-B_Cu.gbr, Esp32Badge-v1-B_Mask.gbr, Esp32Badge-v1-B_Paste.gbr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]
2019-11-23 new sketches and gerbers
    [Esp32Badge-v1-B_Cu.gbr, Esp32Badge-v1-B_Mask.gbr, Esp32Badge-v1-B_Paste.gbr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]
2019-12-01 added kickstand files
    [backplate.stl, kickstand.stl]
2020-01-05 added PCBWay link
2020-01-14 added case link
2020-06-14 added schematic
